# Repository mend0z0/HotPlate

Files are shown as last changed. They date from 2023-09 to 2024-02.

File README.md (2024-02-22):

## Latest update

``
Mainly working on Firmware, but modifying file structures and updating readme files are also on-going...
``

# HotPlate

Hot plate project's purpose is to control the temperature of a hot plate that is used for reflow soldering of PCBs in small numbers. The application
will support a camera for more analysis and study of the process of soldering. The application accepts Gerber, Pick&Place, and BOM, so then the 
user will have a full assembly guideline and also with the connected camera it's possible to confirm the quality and validity of placement and assembly.

## Category

__Assembly Automation__

## Features

- Image processing
- Manual assembly guide
- Controlling over any kind of heaters

## Tech Stack

### Hardware

- **MCU:** PIC18F24J50
- **Connection:** USB, SPI
- **PCB Layers:** 4Layer/s (None-controlled Impedance)
- **CAD:** KiCAD

### Firmware

- **OS:** Super loop
- **Programming Language:** C Language
- **IDE:** MPLABX

### Application

- **IDE:** Qt6
- **Operating System:** Linux/Windows
- **Device:** PC/Laptop

### Mechanical

- **CAD:** Solid Edge
- **Manufacturing Method:** 3D Printing

## Block Diagrams

SystemDesign

Hardware

Firmware

## Screenshots

### Hardware

#### Hardware CAD View

_CADView_HW

#### 3D_View

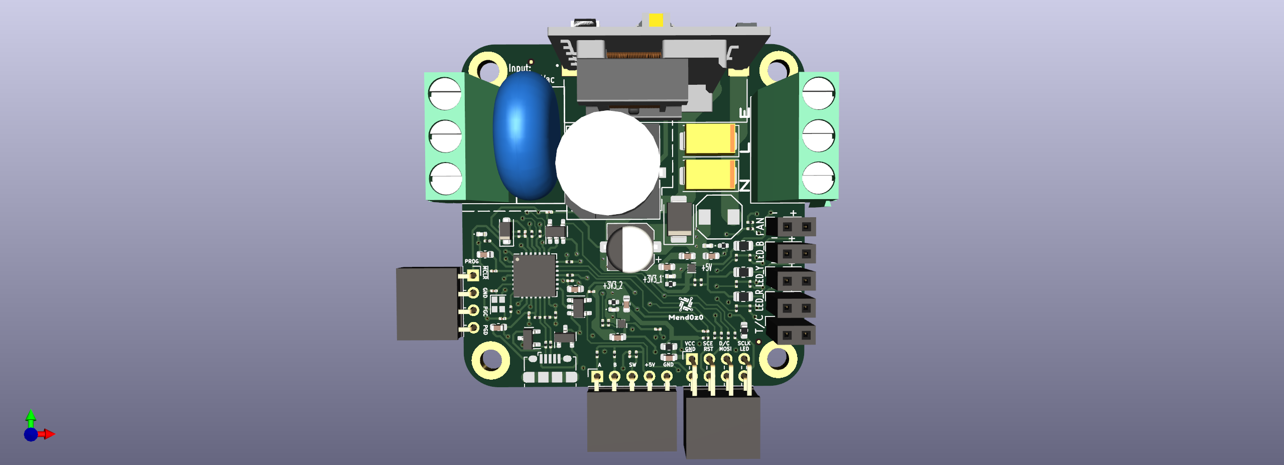
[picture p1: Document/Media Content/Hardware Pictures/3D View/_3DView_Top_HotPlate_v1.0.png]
_3DView_Top


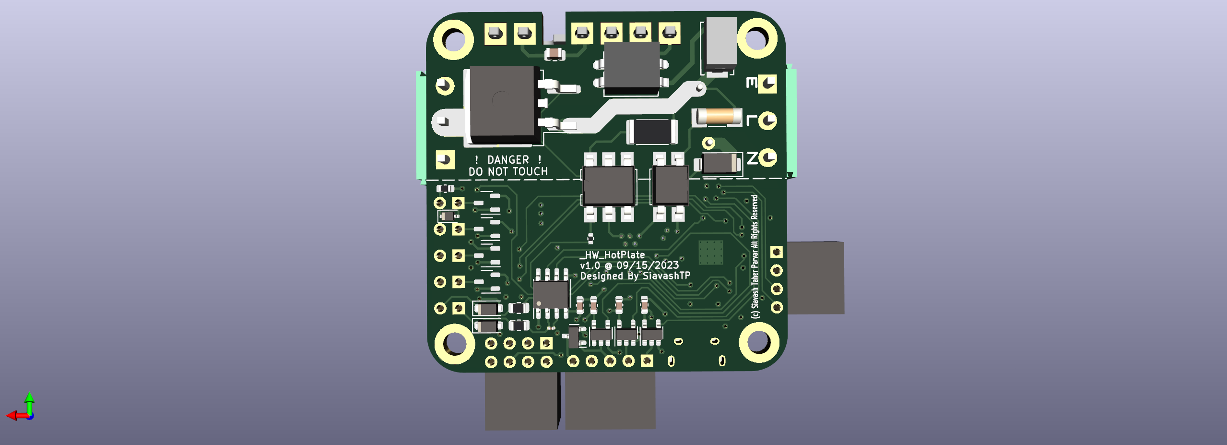
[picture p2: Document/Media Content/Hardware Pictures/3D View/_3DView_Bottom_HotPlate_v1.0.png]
_3DView_Bottom

 
#### Assembled Hardware

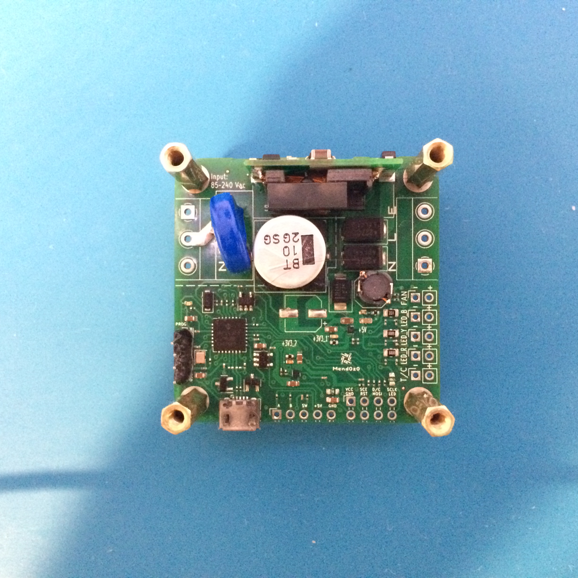
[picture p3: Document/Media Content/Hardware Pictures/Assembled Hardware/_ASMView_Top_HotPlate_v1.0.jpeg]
_ASMView_Top


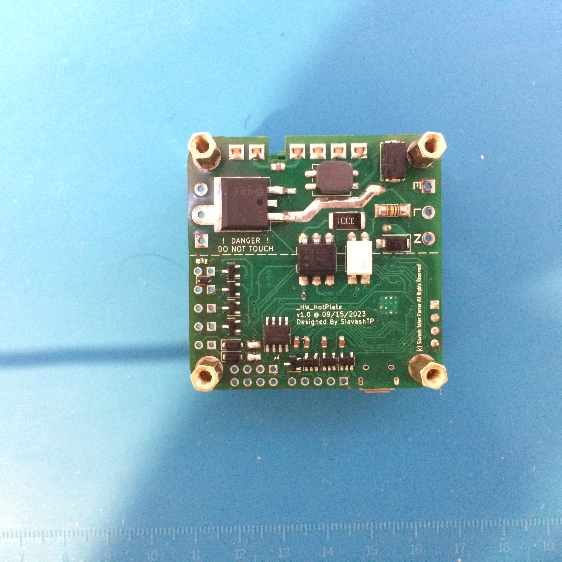
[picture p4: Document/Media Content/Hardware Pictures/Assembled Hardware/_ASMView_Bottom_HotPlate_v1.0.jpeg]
_ASMView_Bottom


### Mechanical CAD View
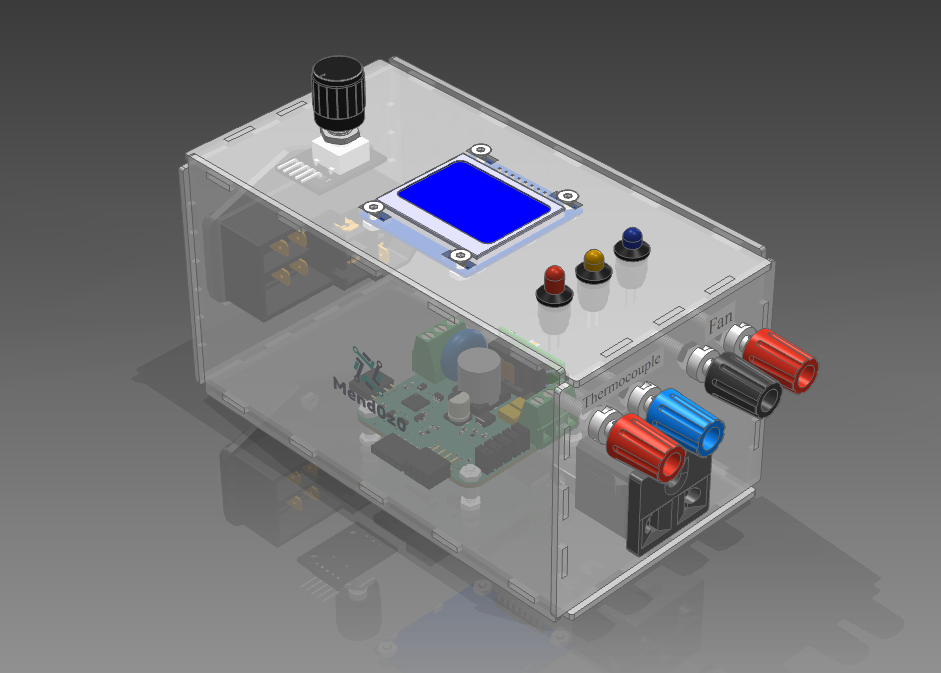
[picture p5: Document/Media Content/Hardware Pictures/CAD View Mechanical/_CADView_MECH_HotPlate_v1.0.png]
_CADView_MECH


### Final Device
_HOTPLATE_

### Application
App Screenshot

## Demo

Demo Test

## LOGO

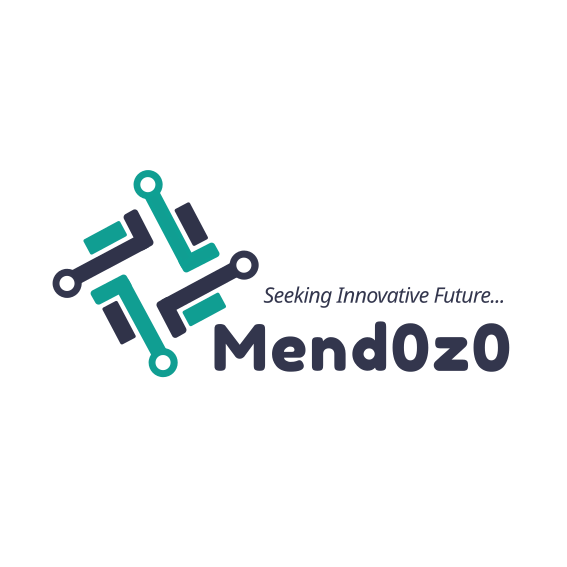
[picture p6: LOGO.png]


## Author

- [@Siavash Taher Parvar](https://www.linkedin.com/in/mend0z0)

## Support

[Support Link](https://github.com/sponsors/mend0z0)

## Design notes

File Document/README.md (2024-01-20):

## This readme file explains the folder structure of Document folder.

#### 1. Block Diagrams: 
	1. _FBD_HW_Prj_vXY.svg
	2. _FBD_SYS_Prj_vXY.svg
	3. _FBD_FW_Prj_vXY.svg

#### 2. Datasheet

#### 3. Media Content: 
	1. Application Screenshot: Screenshots of the Application

	2. Hardware Picture:
		1. 3D View:
			1. _3DView_Top_Prj_vXY.jpeg
			2. _3DView_Bottom_Prj_vXY.jpeg

		2. Assembled Hardware:
			1. _ASMView_Top_Prj_vXY.jpeg
			2. _ASMView_Bottom_Prj_vXY.jpeg

		3. CAD View Hardware:
			1._CADView_HW_Prj_vXY.svg
   
   		4. CAD View Mechanical:
     			1._CADView_MECH_Prj_vXY.svg
	
		5. Full Device
  			1._Prj_vXY.png

	3. Videos
 		1. _VID_Prj_Title_vXY.mp4

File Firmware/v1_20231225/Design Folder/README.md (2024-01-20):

# TODO List

HotPlate firmware project todo list.

## Tasks

- #### MUST to DO (List the works that proper working of project depends on these tasks) :
    - Drawing peripheral functions block diagram (USB, TIMER 0, TIMER 1, TIMER 2, TIMER 3, GPIO, SPI, WDT, EXTI, RTC)
    - Drawing each module/device API/Init functions block diagram (LEDs, FAN, TRIAC, PCD8544, KY-040, MAX31855, Ind LED)
    - Writing C code for the drawn block diagram
    - Writing C code for the ISR
    - Writing C code for the modules/devices
    - Drawing a test scenario for connected modules/devices
    - Writing C code the test scenario block diagram
    - Drawing block diagram for main super-loop
    - Writing C code for the main super-loop block diagram
    - 
    - 
    - 
    - 
    - 
    - 
    - 
    - 
    - 
    - 
    - 
    - 
    - 
    - 
    - 
    - 
    - 
    - 
    - 
    - 
    - 
- #### Important (List the works that efficient and optimized functionality of project depends on these tasks):
    - 
    -
    - 
- #### General (List tasks that are good to be done but the functionality of project doesn't depend on these):
    - 
    -
    -

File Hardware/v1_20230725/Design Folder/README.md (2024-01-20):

# TODO list

HotPlate hardware project todo list.

## Tasks

- #### MUST DO (List the works that proper working of project depends on these tasks):
    - Removing the Header 4x2 from Mechanical parts, and replacing with only 1 recept 1x8.
    - Adding all the mechanical components to the library and schematic.
    - Exporting all the required outputs and finalizing the hardware project.
    - Designing the enclosure in Solidedge.
    - Correcting the stencil outputs. (Next revision)
    - 
- #### Important (List the works that efficient and optimized functionality of project depends on these tasks):
    - Adding 1 more RED LED for +5v power to be placed on the enclosure. (Mechanical parts) (Next revision)
    - Adding 1 more header (2x1, P1.27mm), for +5v output in schematic. (Next revision)
    - Adding Test points for each output power. (Next revision)
    - Correcting the prog pin order according to the output of the programmer. (Next revision)
    - Sizing up the components to 0603 package. (Next revision)
    - Changing the LDO to some bigger package, maybe TL... (Next revision)
    - Modifying the component placement for sure :) (Next revision)
    - Changing the big cap (10uF_400V) to THD. (Next revision)
    - 
- #### General (List tasks that are good to be done but the functionality of project doesn't depend on these):
    - 
    -
    -

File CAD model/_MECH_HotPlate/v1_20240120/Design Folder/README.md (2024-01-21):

# TODO list

A brief description of this todo list belongs to what project

## Tasks

- #### MUST DO (List the works that proper working of project depends on these tasks):
    - Finding Nokia 3D model
    - Finding LEDs (Green, Red, Orange) 3D parts, 5mm
    - Finding LED holder 3d part
    - Rotary encoder 3d part + Knobe
    - Standoff 3d part
    - Screw 3d part
    - Board dimension 150*60*80mm
    - Banana plug 3D part
    - 
    - 
- #### Important (List the works that efficient and optimized functionality of project depends on these tasks):
    - 
    -
    - 
- #### General (List tasks that are good to be done but the functionality of project doesn't depend on these):
    - 
    -
    -

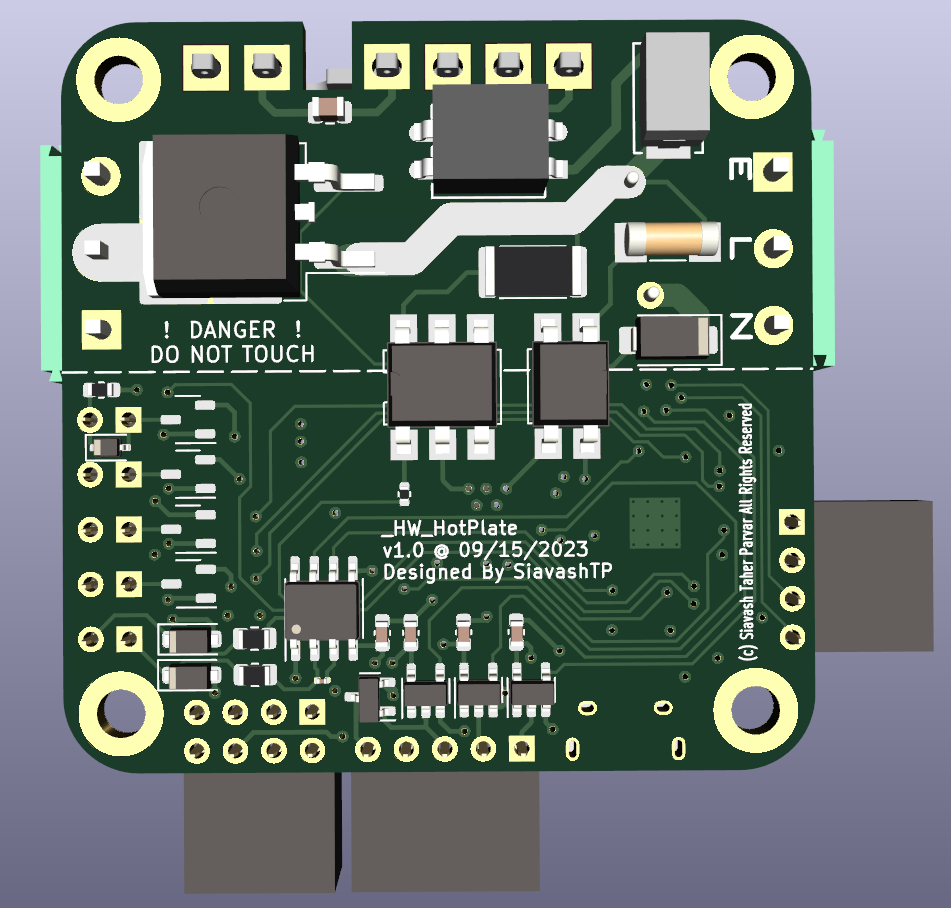
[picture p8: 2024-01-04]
Hardware/v1_20230725/Design Folder/_HW_HotPlate/Output files/3D View/_3DView_Bottom_HotPlate_v1.0 - Copy.png

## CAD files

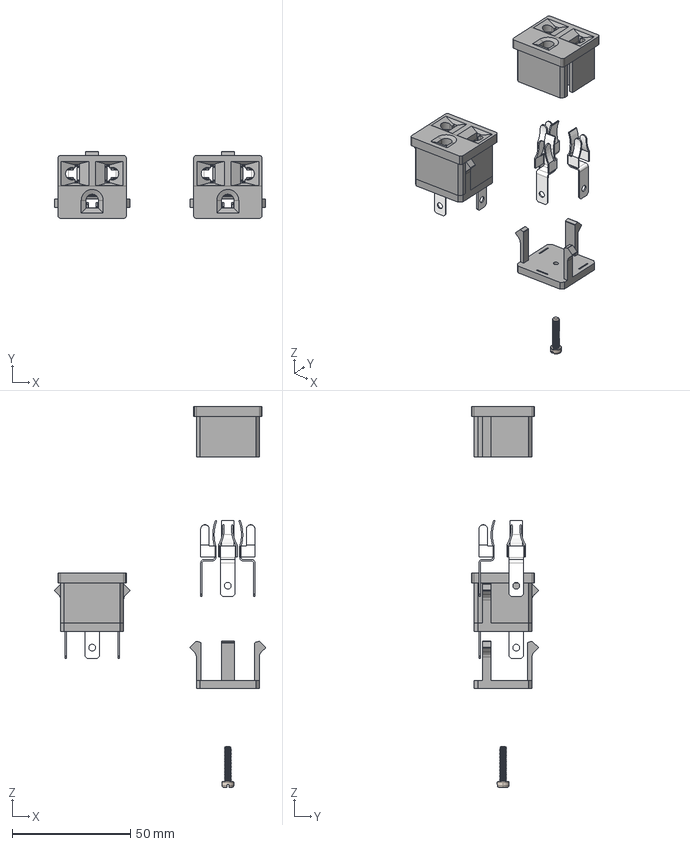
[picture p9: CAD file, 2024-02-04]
CAD model/_MECH_HotPlate/v1_20240120/Design Folder/_MECH_HotPlate/socket-supply.stp
89.4 x 28.2 x 161.2 mm
socket-suplay
Explod Geometry
bak x 2
Screw x 2
pin x 6

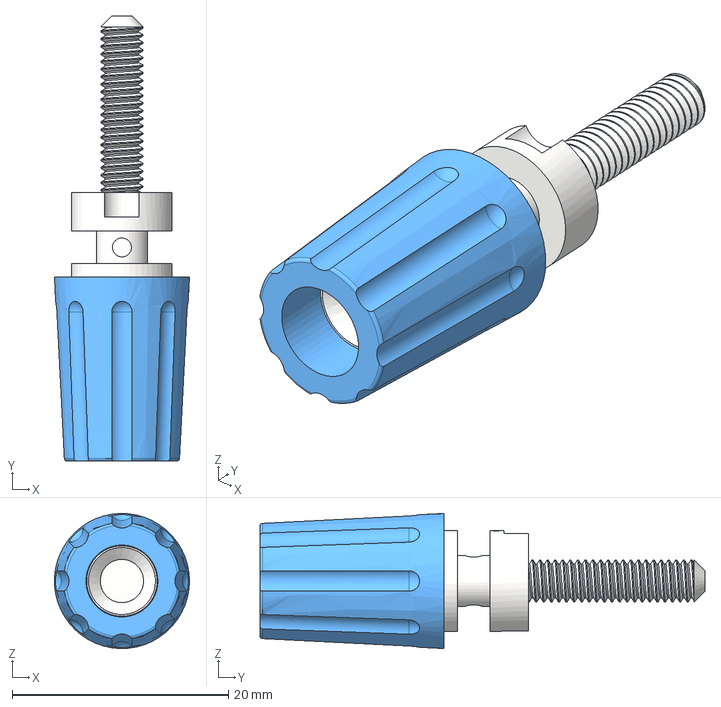
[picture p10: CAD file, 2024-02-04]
CAD model/_MECH_HotPlate/v1_20240120/Design Folder/_MECH_HotPlate/Banana Socket (Blue).step
12.5 x 41.2 x 12.5 mm

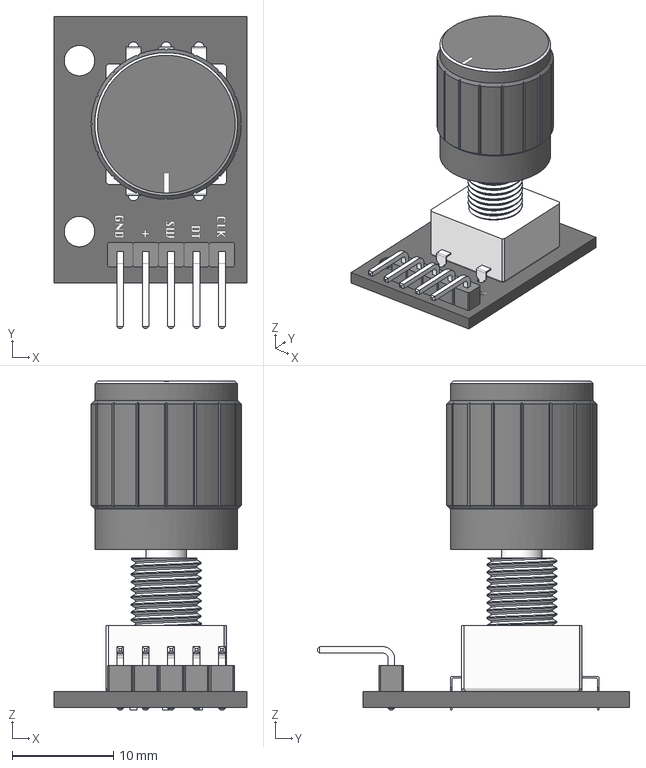
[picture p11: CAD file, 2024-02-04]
CAD model/_MECH_HotPlate/v1_20240120/Design Folder/_MECH_HotPlate/Rotary Encoder - KY-040.step
19.0 x 30.8 x 32.4 mm

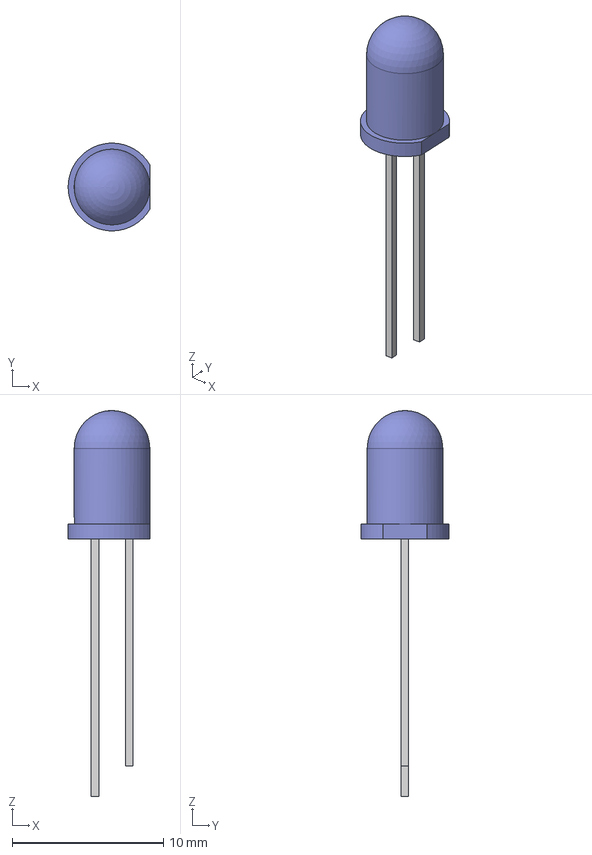
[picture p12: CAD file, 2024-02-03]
CAD model/_MECH_HotPlate/v1_20240120/Design Folder/_MECH_HotPlate/HernanMH_LED 5mm Azul_.step
5.40 x 5.79 x 25.5 mm

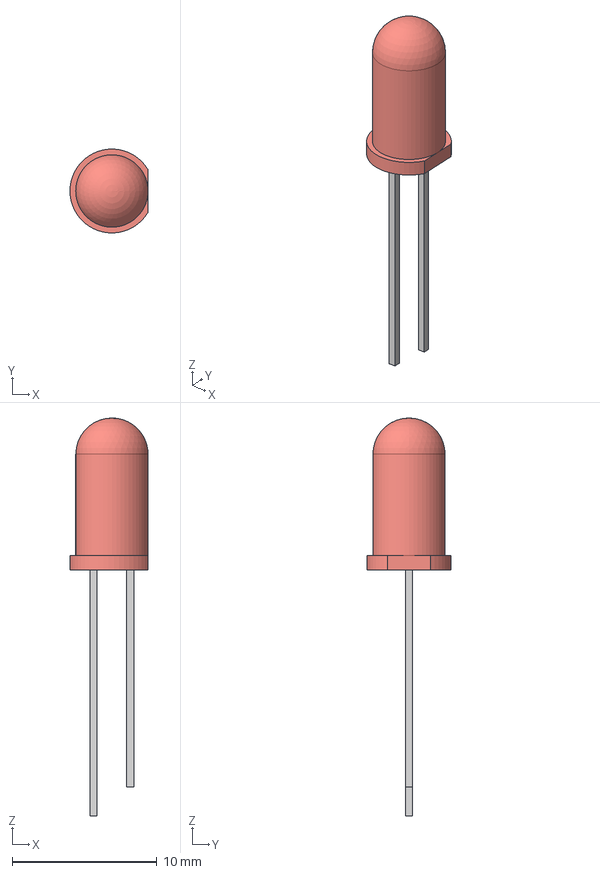
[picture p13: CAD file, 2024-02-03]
CAD model/_MECH_HotPlate/v1_20240120/Design Folder/_MECH_HotPlate/Led 5mm rojo.step
5.40 x 5.79 x 27.5 mm

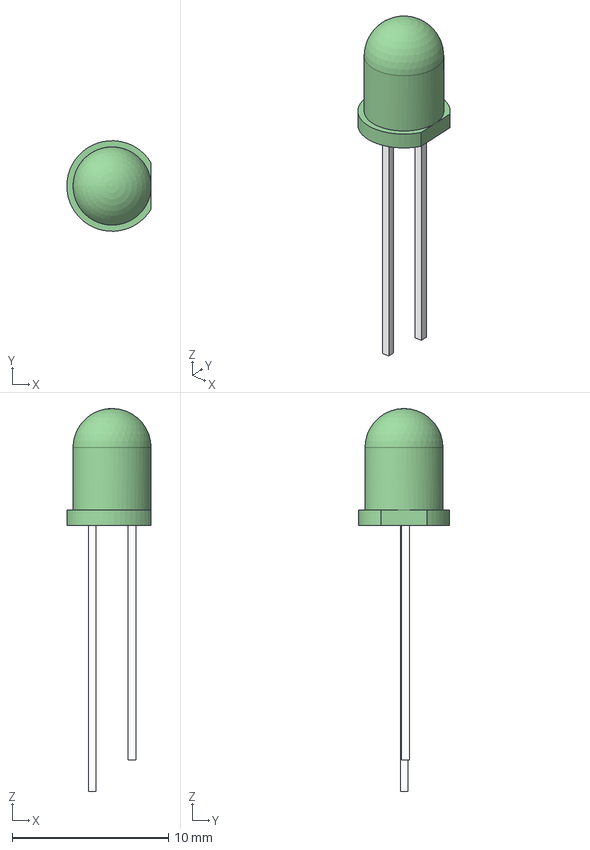
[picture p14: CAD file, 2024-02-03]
CAD model/_MECH_HotPlate/v1_20240120/Design Folder/_MECH_HotPlate/JesusMC_led 5mm v1.step
5.40 x 5.79 x 24.5 mm

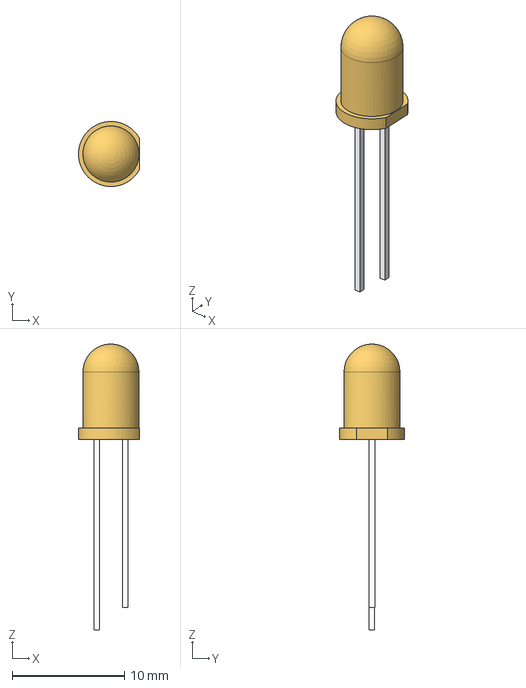
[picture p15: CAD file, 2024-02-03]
CAD model/_MECH_HotPlate/v1_20240120/Design Folder/_MECH_HotPlate/LED5MM v1.step
5.44 x 5.80 x 25.5 mm

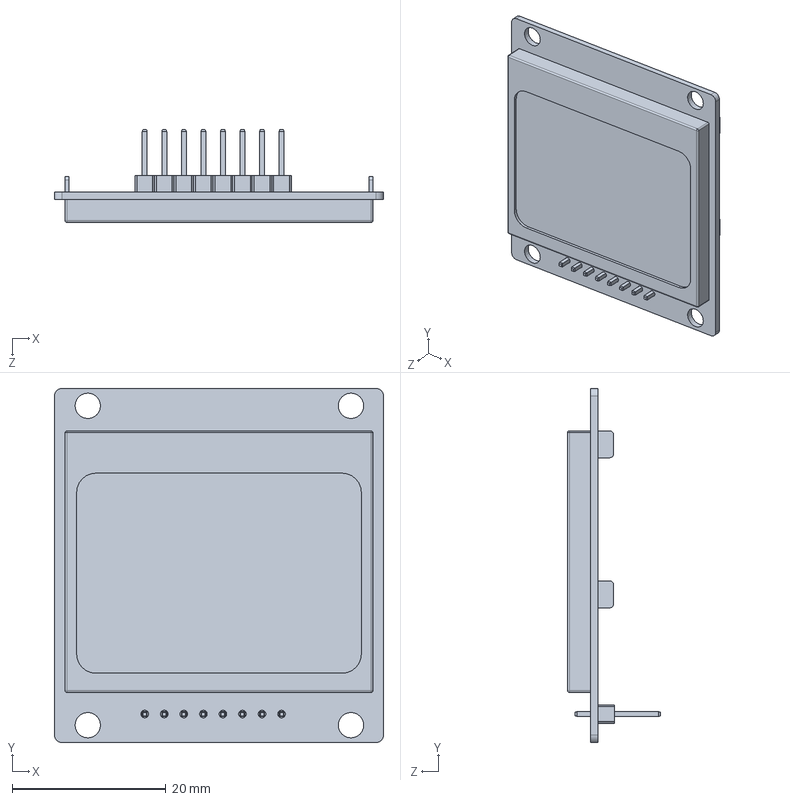
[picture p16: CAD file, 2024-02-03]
CAD model/_MECH_HotPlate/v1_20240120/Design Folder/_MECH_HotPlate/LCD Nokia 5110 Adafruit.SLDPRT
42.8 x 46.0 x 12.1 mm

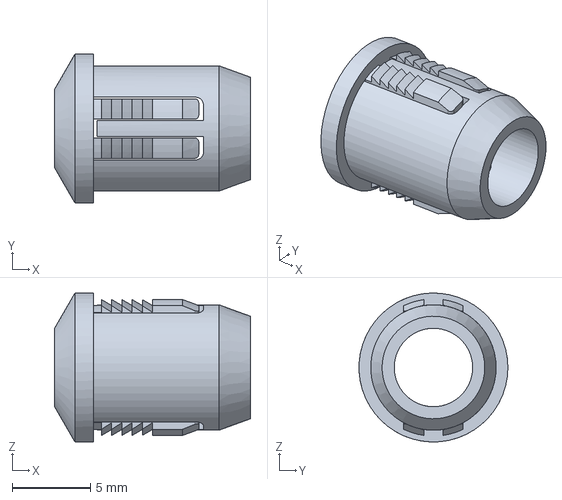
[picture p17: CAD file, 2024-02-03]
CAD model/_MECH_HotPlate/v1_20240120/Design Folder/_MECH_HotPlate/rtf_5010.stp
12.5 x 9.49 x 9.50 mm

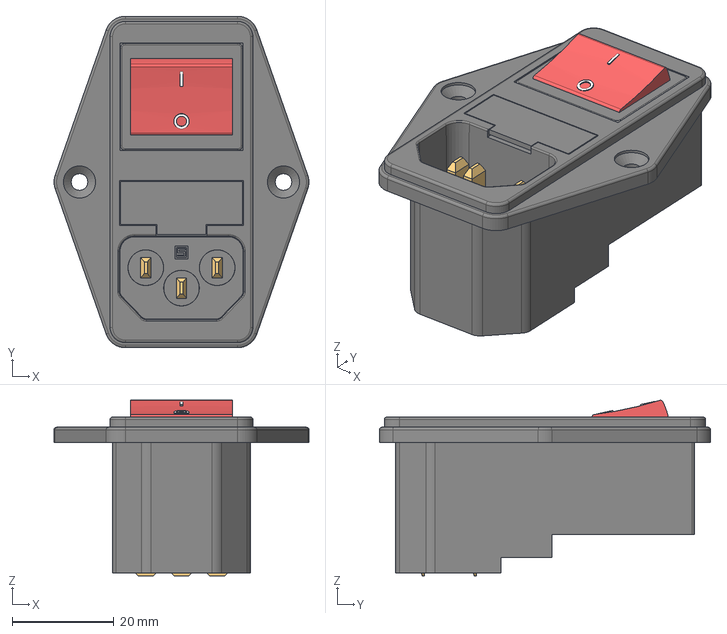
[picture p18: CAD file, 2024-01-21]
CAD model/_MECH_HotPlate/v1_20240120/Design Folder/_MECH_HotPlate/Schurter - 4304.6071 Power Entry Connector Receptacle wth Fuse.stp
50.0 x 65.0 x 34.4 mm

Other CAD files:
CAD model/_MECH_HotPlate/v1_20240120/Design Folder/_MECH_HotPlate/Banana Socket (Black).step
CAD model/_MECH_HotPlate/v1_20240120/Design Folder/_MECH_HotPlate/Banana Socket (Red).step
CAD model/_MECH_HotPlate/v1_20240120/Design Folder/_MECH_HotPlate/m4 lock nut.prt

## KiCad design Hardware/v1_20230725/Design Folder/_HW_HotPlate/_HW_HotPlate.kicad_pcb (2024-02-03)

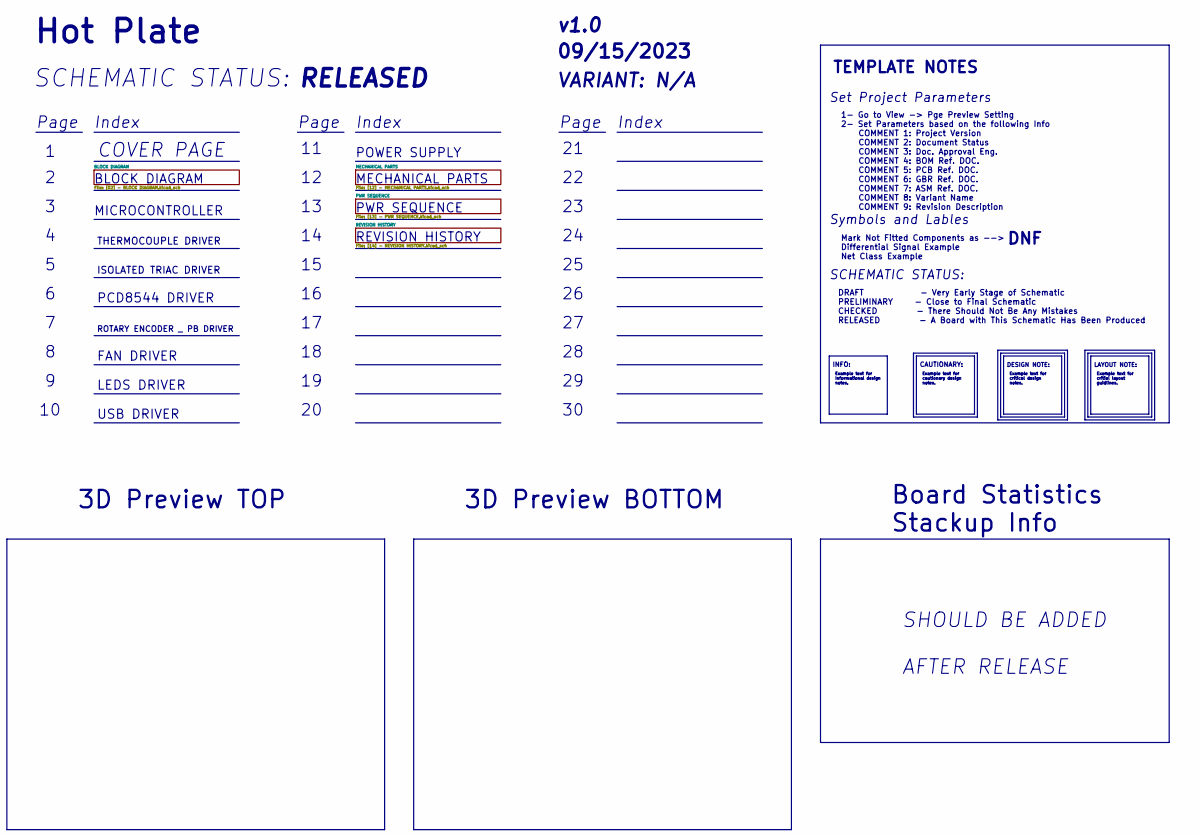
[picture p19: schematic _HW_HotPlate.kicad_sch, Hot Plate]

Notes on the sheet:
USB DRIVER
SHOULD BE ADDED AFTER RELEASE
Set Project Parameters
PCD8544 DRIVER
PWR SEQUENCE
VARIANT: ${COMMENT8}
${REVISION}
Index
Example text for critial layout guidlines.
${TITLE}
DESIGN NOTE:
Page
Board Statistics Stackup Info
REVISION HISTORY
${COMMENT2}
COVER PAGE
SCHEMATIC STATUS:
ISOLATED TRIAC DRIVER
MICROCONTROLLER
LEDS DRIVER
Symbols and Lables
TEMPLATE NOTES
THERMOCOUPLE DRIVER
Mark Not Fitted Components as --> Differential Signal Example Net Class Example
${ISSUE_DATE}
Example text for critical design notes.
Example text for Informational design notes.
Example text for cautionary design notes.
INFO:
SCHEMATIC STATUS:
BLOCK DIAGRAM
FAN DRIVER
3D Preview BOTTOM
1- Go to View -> Pge Preview Setting 2- Set Parameters based on the following Info COMMENT 1: Project Version COMMENT 2: Document Status COMMENT 3: Doc. Approval Eng. COMMENT 4: BOM Ref. DOC. COMMENT 5: PCB Ref. DOC. COMMENT 6: GBR Ref. DOC. COMMENT 7: ASM Ref. DOC. COMMENT 8: Variant Name COMMENT 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
LAYOUT NOTE:
CAUTIONARY:
POWER SUPPLY
DRAFT - Very Early Stage of Schematic PRELIMINARY - Close to Final Schematic CHECKED - There Should Not Be Any Mistakes RELEASED - A Board with This Schematic Has Been Produced
MECHANICAL PARTS
DNF

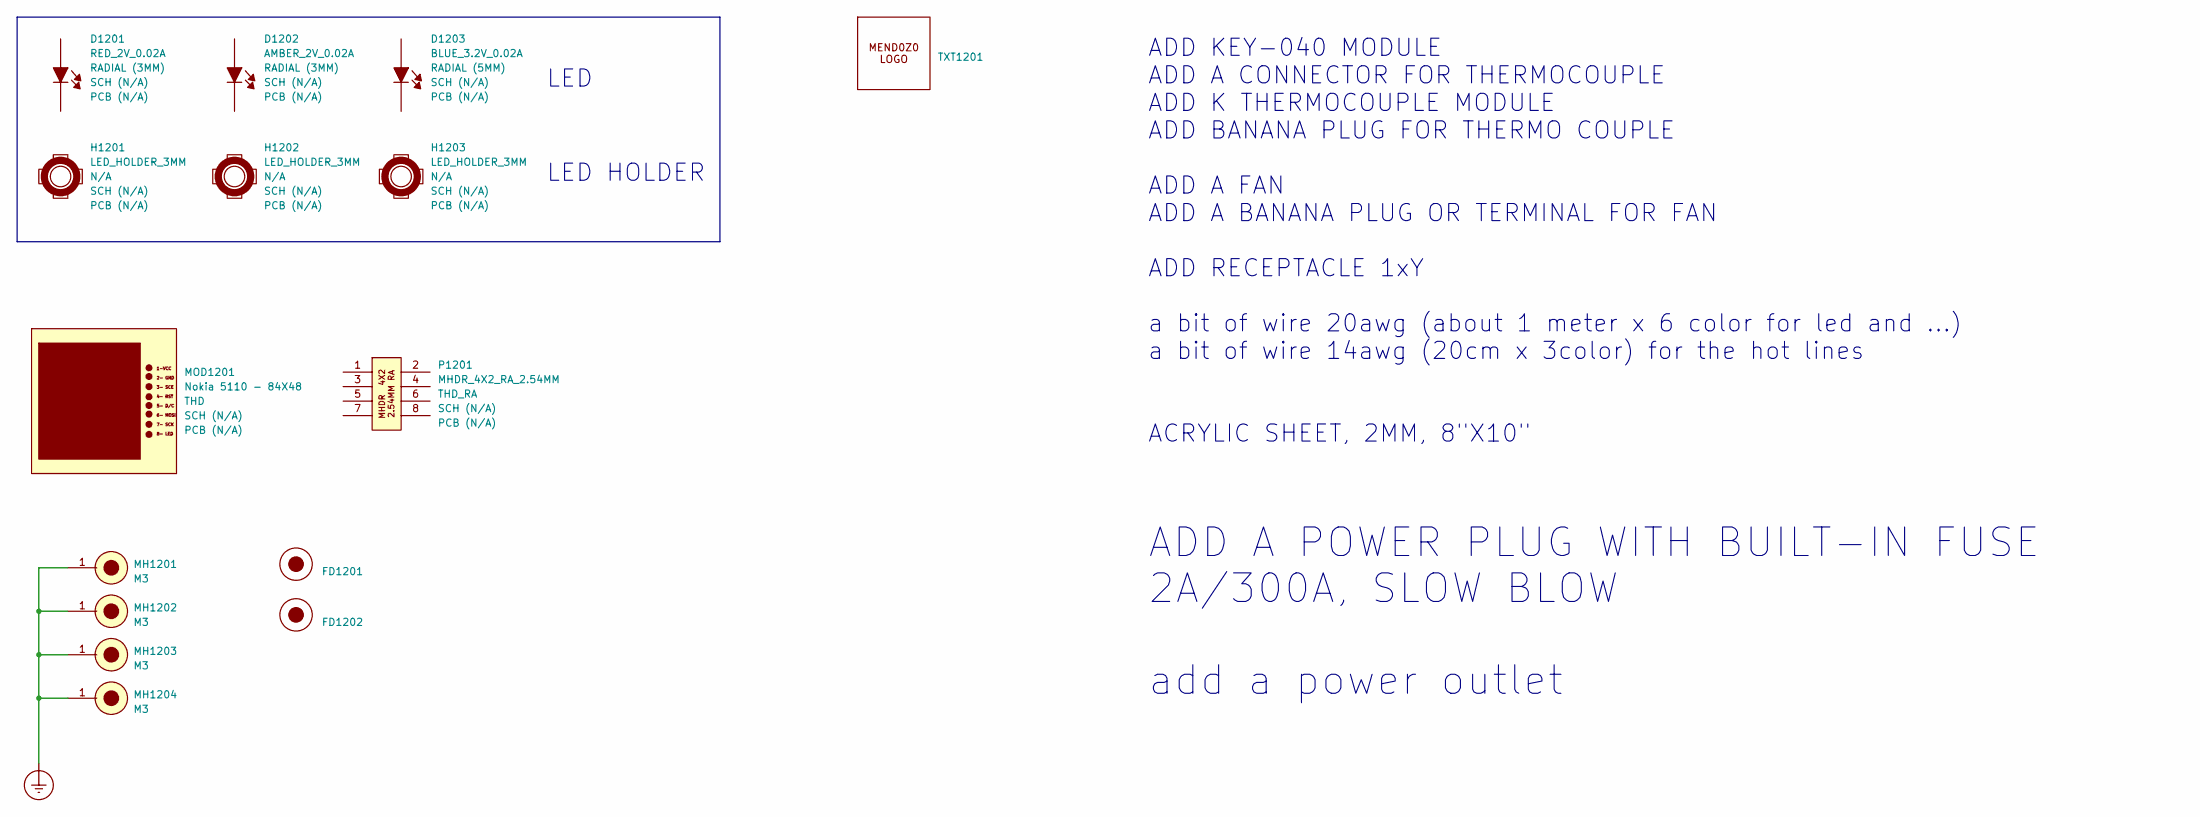
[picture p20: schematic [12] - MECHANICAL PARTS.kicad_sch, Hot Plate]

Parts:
D1201: RED_2V_0.02A; LED_D3.0mm; Part Number (Manufactur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 WP7113ID
D1202: AMBER_2V_0.02A; LED_D3.0mm; Part Number (Manufactur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 BL-BJC1V4V-AT
D1203: BLUE_3.2V_0.02A; LED_D5.0mm; Part Number (Manufactur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 151051BS04000
FD1201, FD1202: Fiducial_0.5mm_Mask1mm
H1201, H1202, H1203: LED_HOLDER_3MM; Part Number (Manufactur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 SSH-LX3050
MH1201, MH1202, MH1203, MH1204: M3; MountingHole_3.2mm_M3_DIN965_Pad_TopBottom
MOD1201: Nokia 5110 - 84X48; Part Number Graphic LCD 84x48 - Nokia 5110
P1201: MHDR_4X2_RA_2.54MM; PinHeader_2x04_P2.54mm_Horizontal; Part Number (Manufactur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 PHED-RS008G1ABOGA-C006
TXT1201: Mend0z0_Logo

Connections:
Earth_Protective: MH1201.1, MH1202.1, MH1203.1, MH1204.1; also elsewhere on the board

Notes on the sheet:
LED
ADD KEY-040 MODULE ADD A CONNECTOR FOR THERMOCOUPLE ADD K THERMOCOUPLE MODULE ADD BANANA PLUG FOR THERMO COUPLE ADD A FAN ADD A BANANA PLUG OR TERMINAL FOR FAN ADD RECEPTACLE 1xY a bit of wire 20awg (about 1 meter x 6 color for led and ...) a bit of wire 14awg (20cm x 3color) for the hot lines ACRY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
LED HOLDER
ADD A POWER PLUG WITH BUILT-IN FUSE 2A/300A, SLOW BLOW add a power outlet

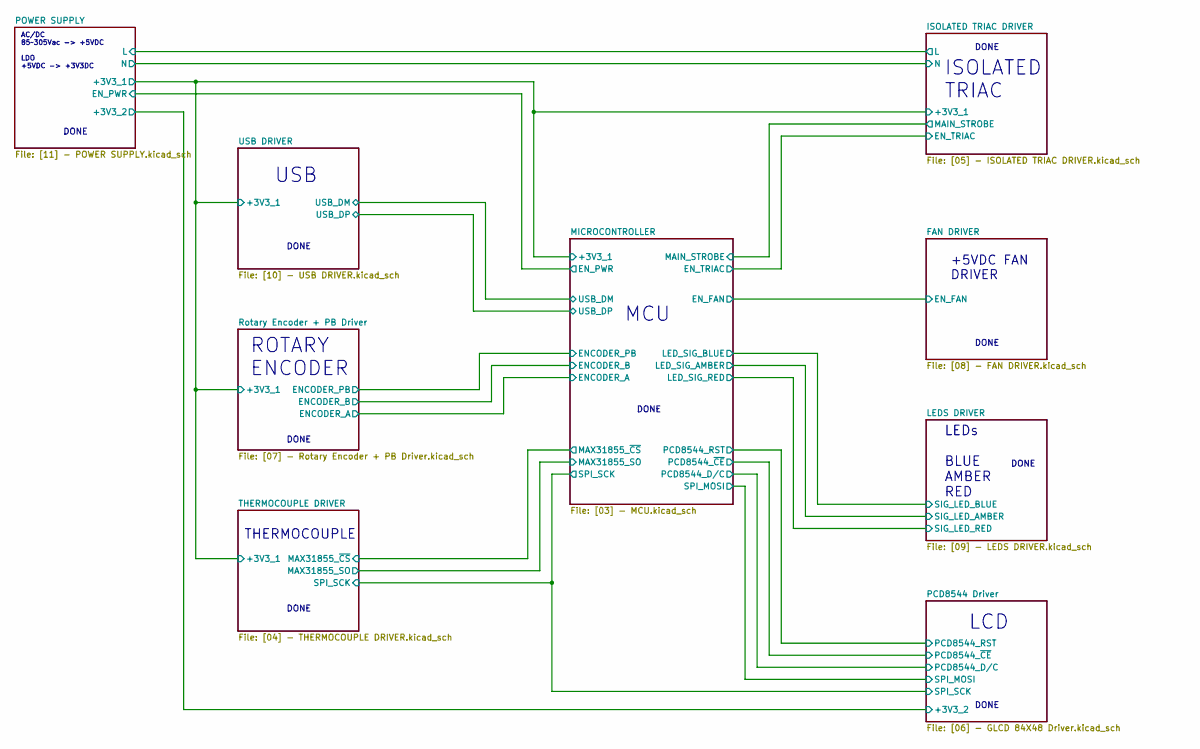
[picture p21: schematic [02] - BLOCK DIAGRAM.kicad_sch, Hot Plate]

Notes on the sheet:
DONE
MCU
THERMOCOUPLE
AC/DC 85~305Vac -> +5VDC LDO +5VDC -> +3V3DC
USB
LCD
ROTARY ENCODER
ISOLATED TRIAC
LEDs BLUE AMBER RED
+5VDC FAN DRIVER

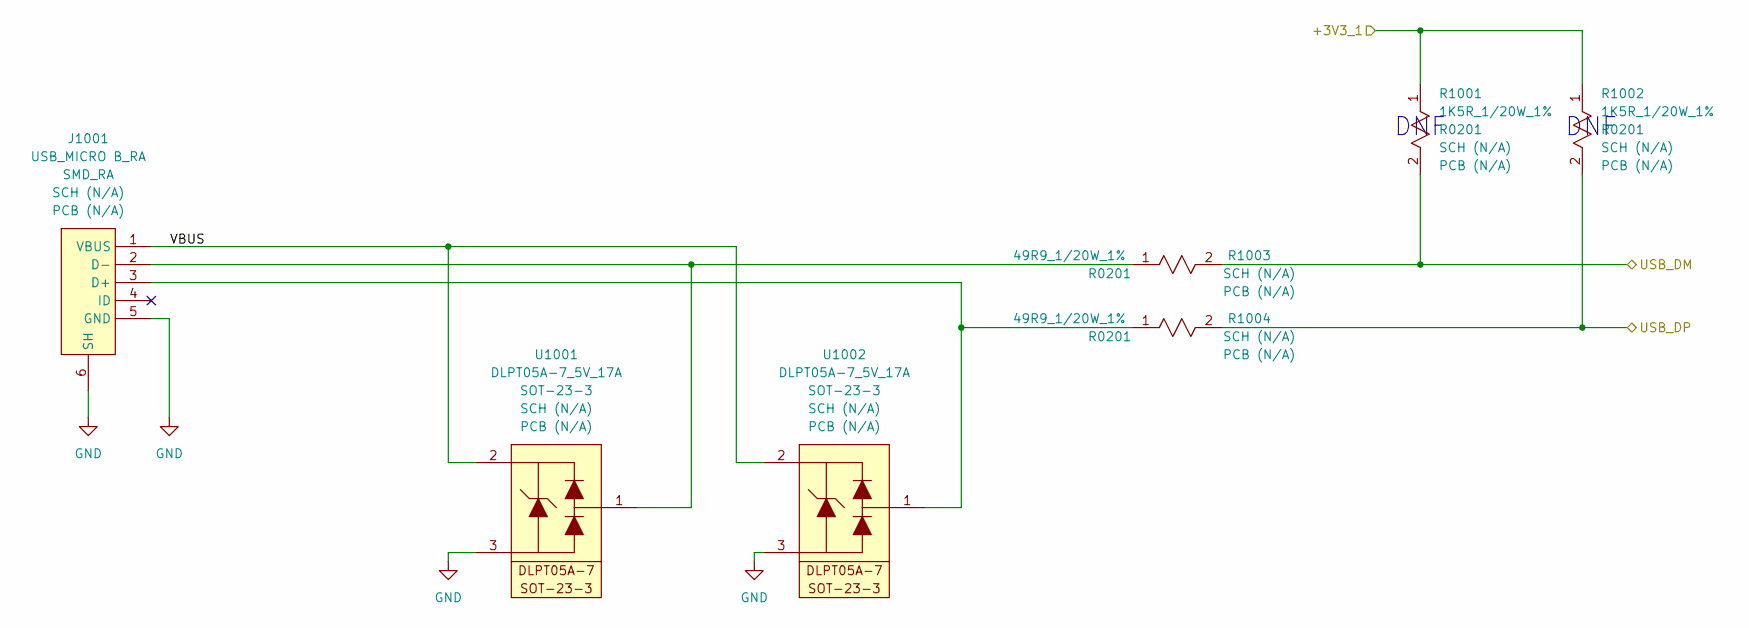
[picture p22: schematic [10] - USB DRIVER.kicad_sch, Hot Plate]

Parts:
J1001: USB_MICRO B_RA; USB_Micro-B_Amphenol_10118194_Horizontal; Part Number (Manufactur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 10118194-0001LF
R1001, R1002: 1K5R_1/20W_1%; R_0201_0603Metric; Part Number (Manufactur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 RC0201FR-071K4L
R1003, R1004: 49R9_1/20W_1%; R_0201_0603Metric; Part Number (Manufactur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 RMCF0201FT49R9
U1001, U1002: DLPT05A-7_5V_17A; SOT-23; Part Number (Manufactur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 DLPT05A-7

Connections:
/BLOCK DIAGRAM/ISOLATED TRIAC DRIVER/+3V3_1: R1001.1, R1002.1; also elsewhere on the board
/BLOCK DIAGRAM/MICROCONTROLLER/USB_DM: R1001.2, R1003.2; also elsewhere on the board
/BLOCK DIAGRAM/MICROCONTROLLER/USB_DP: R1002.2, R1004.2; also elsewhere on the board
/BLOCK DIAGRAM/USB DRIVER/VBUS: J1001.1 (VBUS), U1001.2, U1002.2
unnamed: J1001.3 (D+), R1004.1, U1002.1
unnamed: J1001.2 (D-), R1003.1, U1001.1

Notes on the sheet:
DNF

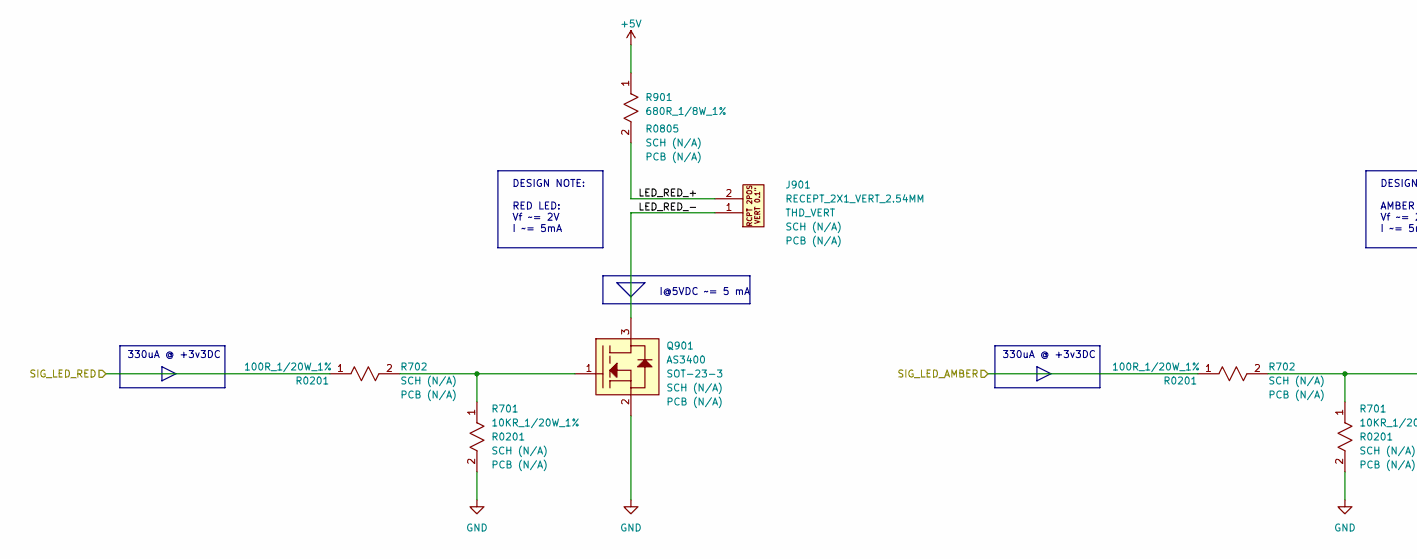
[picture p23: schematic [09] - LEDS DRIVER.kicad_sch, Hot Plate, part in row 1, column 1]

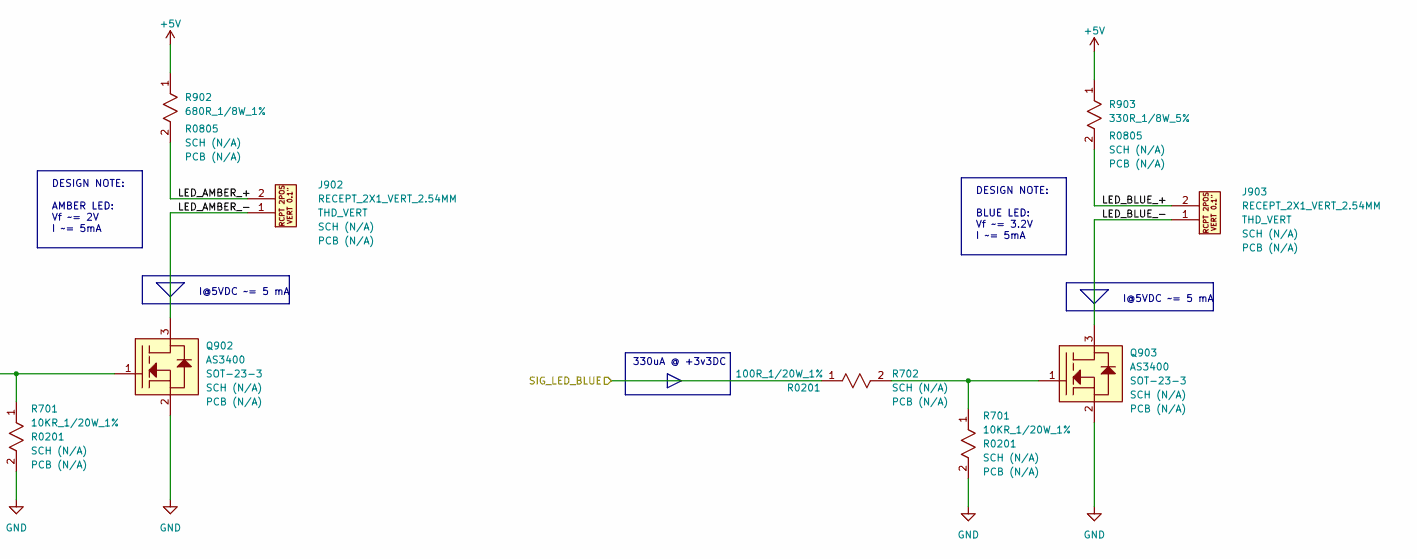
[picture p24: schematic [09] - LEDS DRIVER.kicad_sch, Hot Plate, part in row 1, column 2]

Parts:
J901, J902, J903: RECEPT_2X1_VERT_2.54MM; PinSocket_1x02_P2.54mm_Vertical; Part Number (Manufactur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 RS1-02-G
Q901, Q902, Q903: AS3400; SOT-23; Part Number (Manufactur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 AS3400
R701: 10KR_1/20W_1%; R_0201_0603Metric; Part Number (Manufactur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 RMCF0201FT10K0
R702: 100R_1/20W_1%; R_0201_0603Metric; Part Number (Manufactur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 RMCF0201FT100R
R901, R902: 680R_1/8W_1%; R_0805_2012Metric; Part Number (Manufactur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 AC0805FR-07680RL
R903: 330R_1/8W_5%; R_0805_2012Metric; Part Number (Manufactur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 CRGCQ0805J330R

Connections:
/BLOCK DIAGRAM/LEDS DRIVER/LED_AMBER_+: J902.2, R902.2
/BLOCK DIAGRAM/LEDS DRIVER/LED_AMBER_-: J902.1, Q902.3
/BLOCK DIAGRAM/LEDS DRIVER/LED_RED_+: J901.2, R901.2
/BLOCK DIAGRAM/LEDS DRIVER/LED_RED_-: J901.1, Q901.3
unnamed 68: R702.1; also elsewhere on the board

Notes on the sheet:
DESIGN NOTE: AMBER LED: Vf ~= 2V I ~= 5mA
I@5VDC ~= 5 mA
DESIGN NOTE: BLUE LED: Vf ~= 3.2V I ~= 5mA
330uA @ +3v3DC
DESIGN NOTE: RED LED: Vf ~= 2V I ~= 5mA

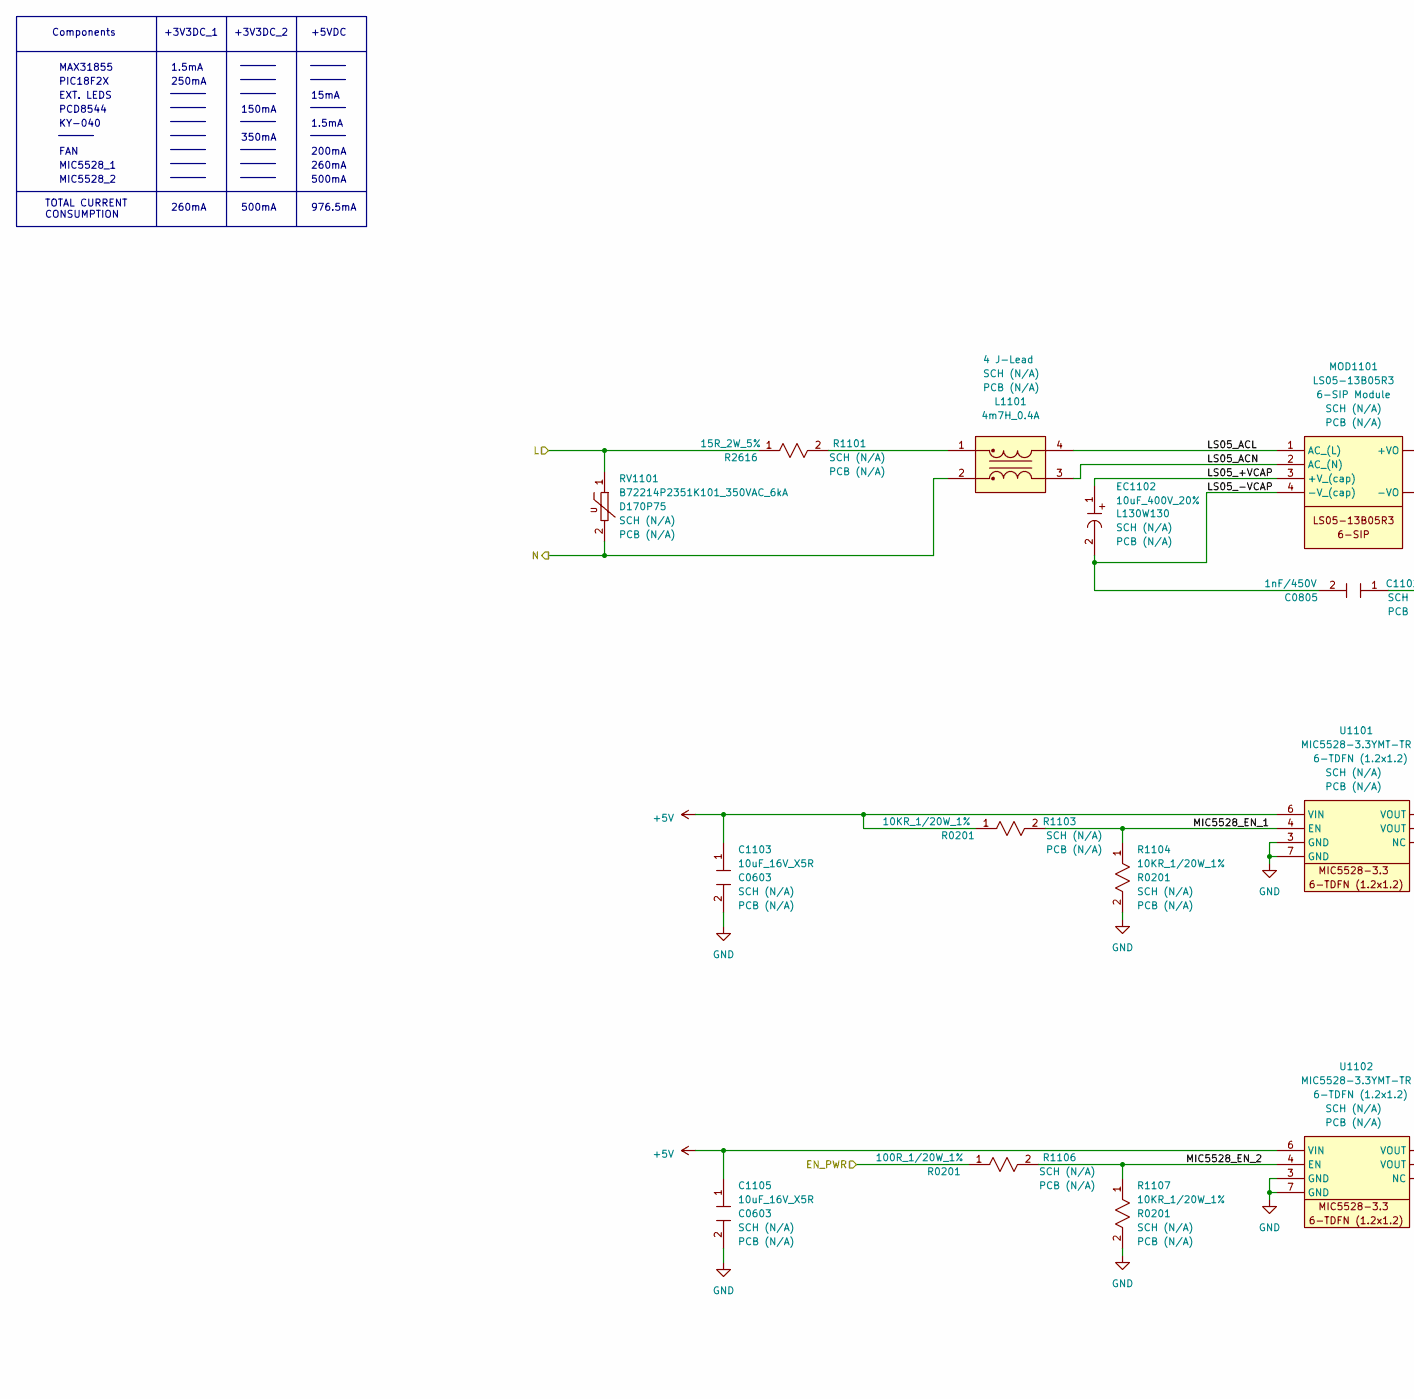
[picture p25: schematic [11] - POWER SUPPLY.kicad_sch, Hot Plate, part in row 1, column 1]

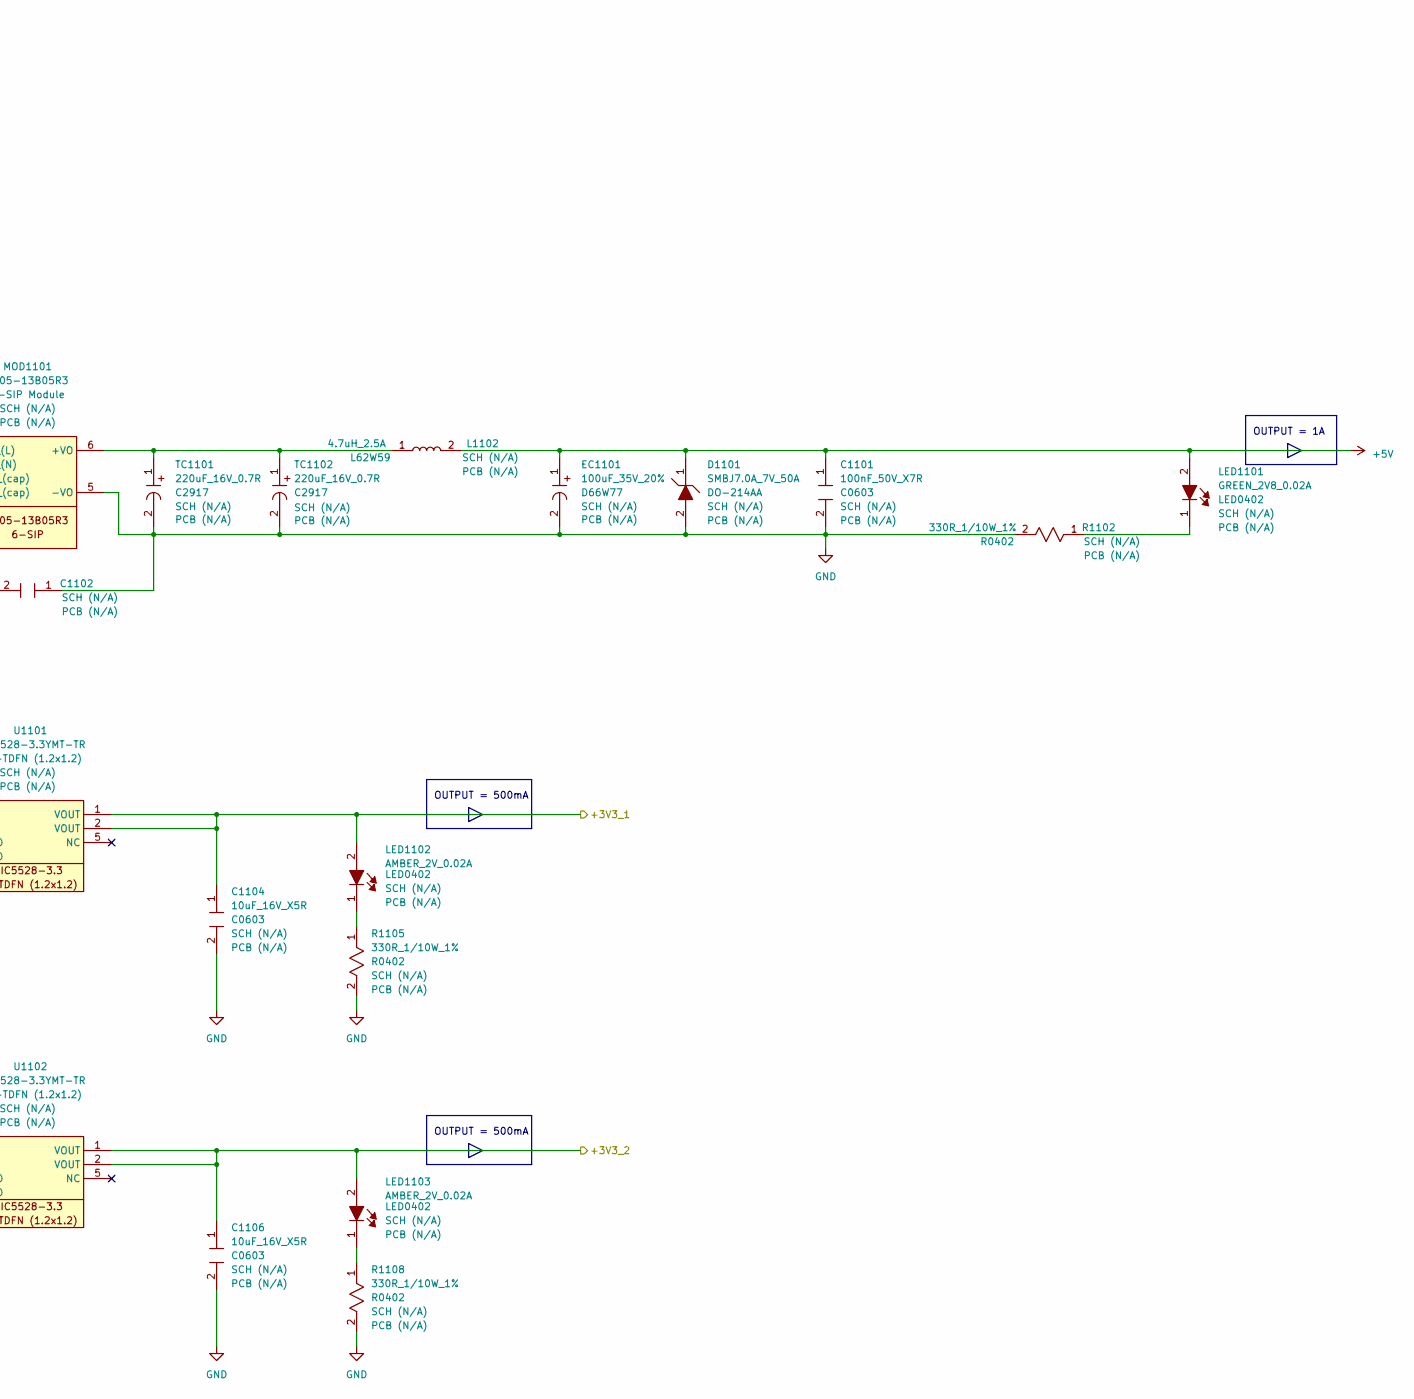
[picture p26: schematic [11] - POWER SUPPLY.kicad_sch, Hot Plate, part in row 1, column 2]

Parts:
C1101: 100nF_50V_X7R; C_0603_1608Metric; Part Number (Manufactur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 CL10B104KB8NNNC
C1102: 1nF/450V; C_0805_2012Metric; Part Number CGA4C4C0G2W102J060AE
C1103, C1104, C1105, C1106: 10uF_16V_X5R; C_0603_1608Metric; Part Number (Manufactur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 GRT188R61C106KE13J
D1101: SMBJ7.0A_7V_50A; D_SMB; Part Number (Manufactur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 SMBJ7.0A
EC1101: 100uF_35V_20%; CP_Elec_6.3x7.7; Part Number (Manufactur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 AFK107M35X16T-F
EC1102: 10uF_400V_20%; CAP_S-V_12P5X13P5_RUB; Part Number (Manufactur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 400SGV10M12.5X13.5
L1101: 4m7H_0.4A; IND_50XXXC_MUR; Part Number (Manufactur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 50475C
L1102: 4.7uH_2.5A; IND_6045_TDK; Part Number (Manufactur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 CLF6045T-4R7N-H
LED1101: GREEN_2V8_0.02A; LED_0402_1005Metric; Part Number (Manufactur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 B2841NG--05D000514U1930
LED1102, LED1103: AMBER_2V_0.02A; LED_0402_1005Metric; Part Number (Manufactur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 B2841UY--20D000414U1930
MOD1101: LS05-13B05R3; CONV_LS05-13B05R3; Part Number (Manufactur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 LS05-13B05R3
R1101: 15R_2W_5%; RES_SMF2_TYCO_TYC; Part Number (Manufactur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 SMW215RJT
R1102, R1105, R1108: 330R_1/10W_1%; R_0402_1005Metric; Part Number (Manufactur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 ERJ-2RKF3300X
R1103, R1104, R1107: 10KR_1/20W_1%; R_0201_0603Metric; Part Number (Manufactur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 RMCF0201FT10K0
R1106: 100R_1/20W_1%; R_0201_0603Metric; Part Number (Manufactur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 RMCF0201FT100R
RV1101: B72214P2351K101_350VAC_6kA; RV_Disc_D16.5mm_W6.7mm_P7.5mm; Part Number (Manufactur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 B72214P2351K101
TC1101, TC1102: 220uF_16V_0.7R; CP_EIA-7343-30_AVX-N; Part Number (Manufactur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 F931C227MNC
U1101, U1102: MIC5528-3.3YMT-TR; DFN-6-1EP_1.2x1.2mm_P0.4mm_EP0.3x0.94mm_PullBack; Part Number (Manufactur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 MIC5528-3.3YMT-TR

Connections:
/BLOCK DIAGRAM/ISOLATED TRIAC DRIVER/+3V3_1: C1104.1, LED1102.2, U1101.1 (VOUT), U1101.2 (VOUT); also elsewhere on the board
/BLOCK DIAGRAM/ISOLATED TRIAC DRIVER/L_IN: R1101.1, RV1101.1; also elsewhere on the board
/BLOCK DIAGRAM/ISOLATED TRIAC DRIVER/N: L1101.2, RV1101.2; also elsewhere on the board
/BLOCK DIAGRAM/MICROCONTROLLER/EN_PWR: R1106.1; also elsewhere on the board
/BLOCK DIAGRAM/PCD8544 Driver/+3V3_2: C1106.1, LED1103.2, U1102.1 (VOUT), U1102.2 (VOUT); also elsewhere on the board
/BLOCK DIAGRAM/POWER SUPPLY/LS05_+VCAP: EC1102.1, MOD1101.3 (+V_(cap))
/BLOCK DIAGRAM/POWER SUPPLY/LS05_-VCAP: C1102.2, EC1102.2, MOD1101.4 (-V_(cap))
/BLOCK DIAGRAM/POWER SUPPLY/LS05_ACL: L1101.4, MOD1101.1 (AC_(L))
/BLOCK DIAGRAM/POWER SUPPLY/LS05_ACN: L1101.3, MOD1101.2 (AC_(N))
/BLOCK DIAGRAM/POWER SUPPLY/MIC5528_EN_1: R1103.2, R1104.1, U1101.4 (EN)
/BLOCK DIAGRAM/POWER SUPPLY/MIC5528_EN_2: R1106.2, R1107.1, U1102.4 (EN)
unnamed: L1101.1, R1101.2
unnamed: LED1101.1, R1102.1
unnamed: LED1102.1, R1105.1
unnamed: LED1103.1, R1108.1
unnamed: L1102.1, MOD1101.6 (+VO), TC1101.1, TC1102.1

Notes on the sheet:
+5VDC
500mA
260mA
350mA
1.5mA
PIC18F2X
TOTAL CURRENT CONSUMPTION
EXT. LEDS
150mA
Components
200mA
+3V3DC_1
FAN
15mA
OUTPUT = 500mA
976.5mA
+3V3DC_2
MIC5528_1
PCD8544
250mA
OUTPUT = 1A
MAX31855
MIC5528_2
KY-040

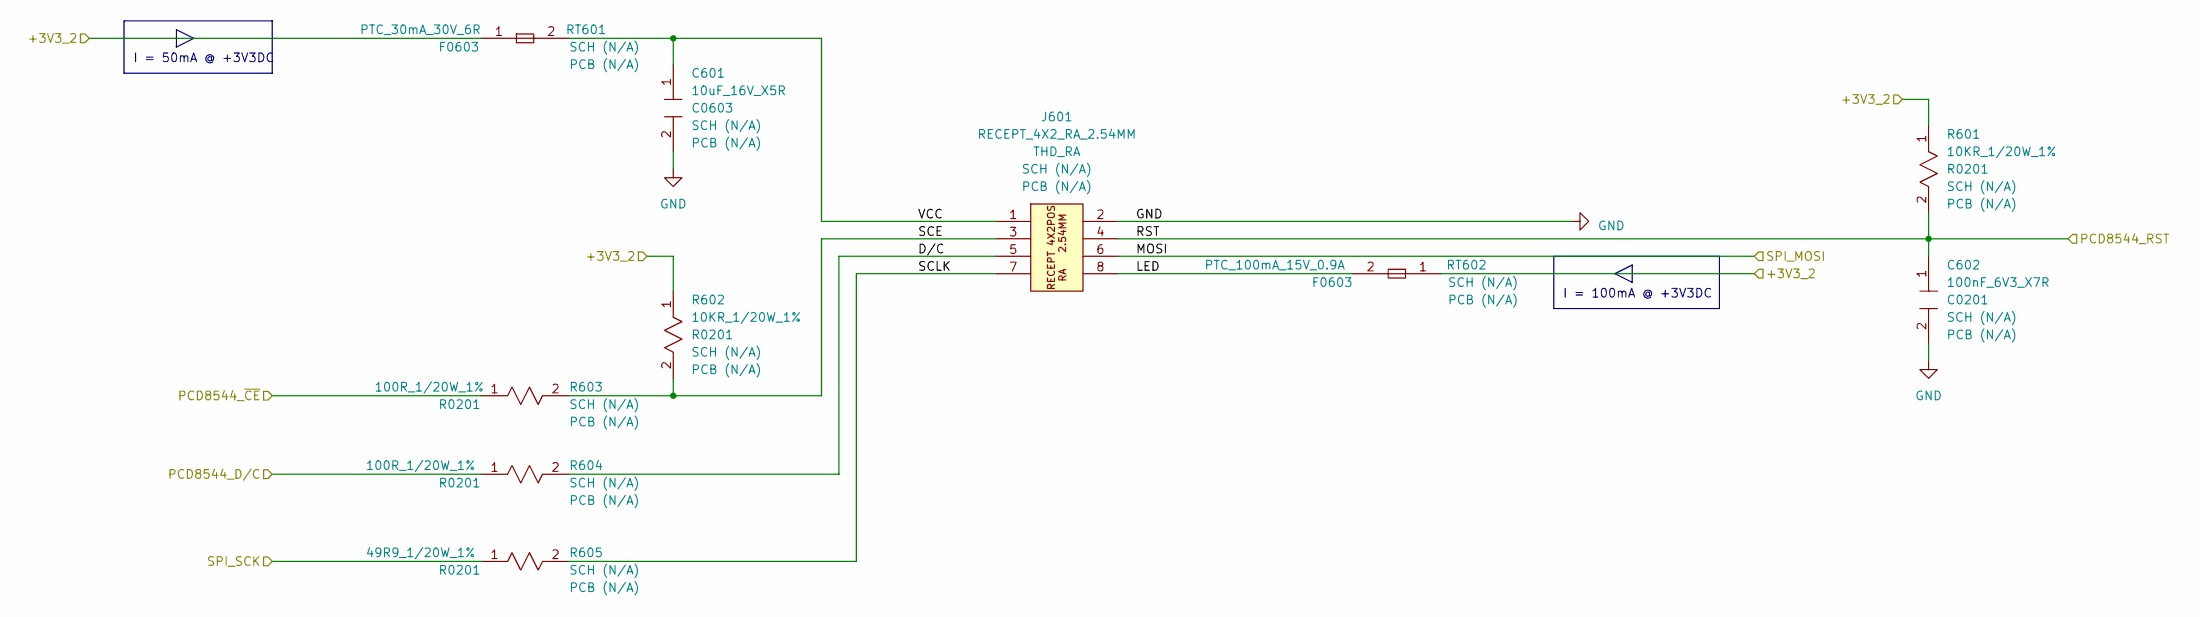
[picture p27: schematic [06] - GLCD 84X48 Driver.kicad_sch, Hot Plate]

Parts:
C601: 10uF_16V_X5R; C_0603_1608Metric; Part Number (Manufactur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 GRT188R61C106KE13J
C602: 100nF_6V3_X7R; C_0201_0603Metric; Part Number (Manufactur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 CC0201KRX7R5BB104
J601: RECEPT_4X2_RA_2.54MM; PinSocket_2x04_P2.54mm_Horizontal; Part Number (Manufactur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 PPTC042LJBN-RC
R601, R602: 10KR_1/20W_1%; R_0201_0603Metric; Part Number (Manufactur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 RMCF0201FT10K0
R603, R604: 100R_1/20W_1%; R_0201_0603Metric; Part Number (Manufactur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 RMCF0201FT100R
R605: 49R9_1/20W_1%; R_0201_0603Metric; Part Number (Manufactur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 RMCF0201FT49R9
RT601: PTC_30mA_30V_6R; Fuse_0603_1608Metric; Part Number (Manufactur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 0ZCM0003FF2G
RT602: PTC_100mA_15V_0.9A; Fuse_0603_1608Metric; Part Number (Manufactur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 0ZCM0010FF2G

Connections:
/BLOCK DIAGRAM/MICROCONTROLLER/PCD8544_D/C: R604.1; also elsewhere on the board
/BLOCK DIAGRAM/MICROCONTROLLER/PCD8544_~CE: R603.1; also elsewhere on the board
/BLOCK DIAGRAM/MICROCONTROLLER/SPI_SCK: R605.1; also elsewhere on the board
/BLOCK DIAGRAM/PCD8544 Driver/+3V3_2: R601.1, R602.1, RT601.1, RT602.1; also elsewhere on the board
/BLOCK DIAGRAM/PCD8544 Driver/D/C: J601.5, R604.2
/BLOCK DIAGRAM/PCD8544 Driver/LED: J601.8, RT602.2
/BLOCK DIAGRAM/PCD8544 Driver/MOSI: J601.6; also elsewhere on the board
/BLOCK DIAGRAM/PCD8544 Driver/RST: C602.1, J601.4, R601.2; also elsewhere on the board
/BLOCK DIAGRAM/PCD8544 Driver/SCE: J601.3, R602.2, R603.2
/BLOCK DIAGRAM/PCD8544 Driver/SCLK: J601.7, R605.2
/BLOCK DIAGRAM/PCD8544 Driver/VCC: C601.1, J601.1, RT601.2

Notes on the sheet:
I = 100mA @ +3V3DC
I = 50mA @ +3V3DC

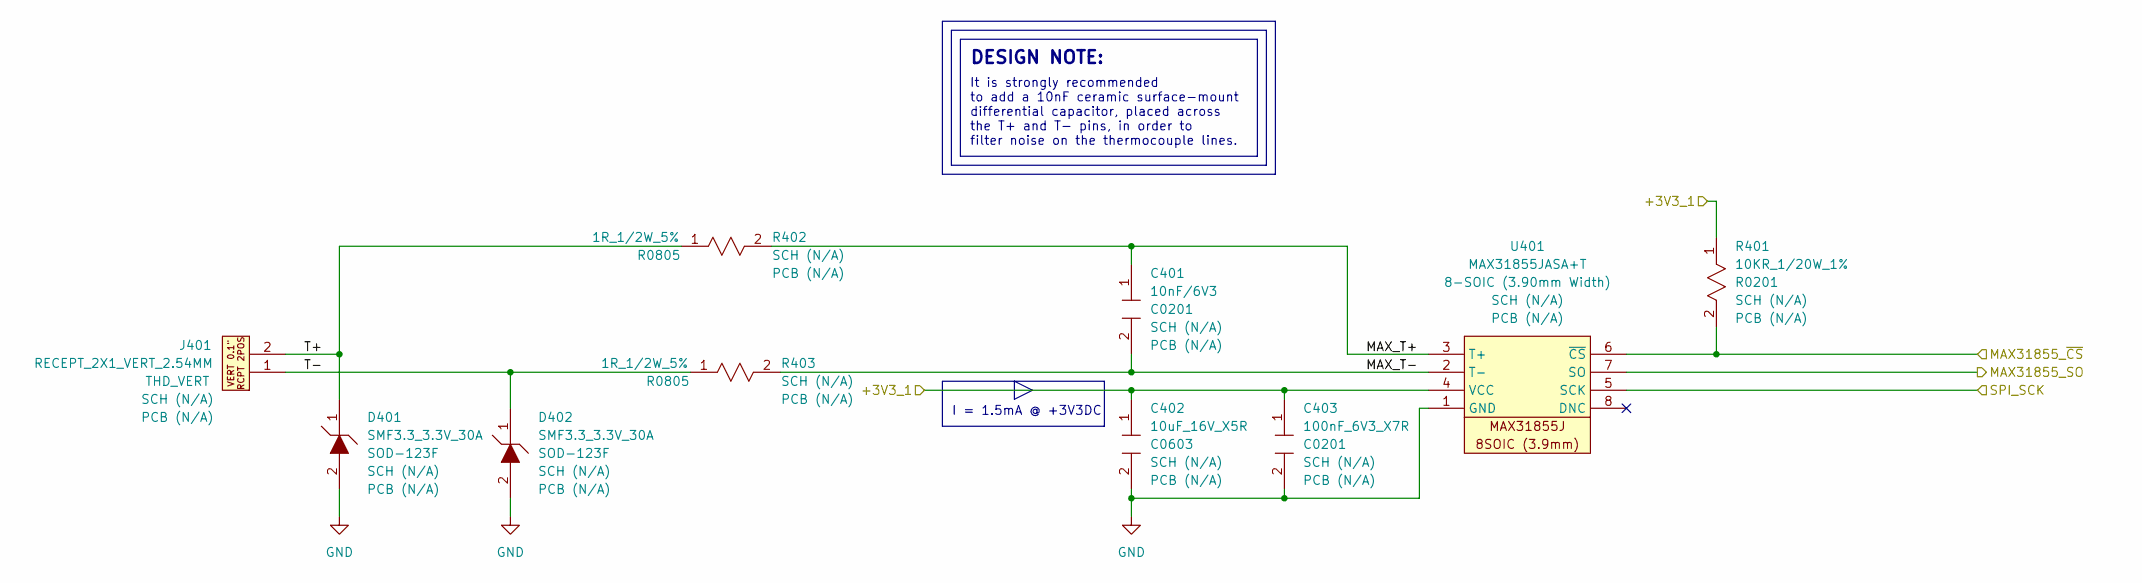
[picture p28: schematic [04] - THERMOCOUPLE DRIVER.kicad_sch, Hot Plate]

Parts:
C401: 10nF/6V3; C_0201_0603Metric; Part Number (Manufactur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 0201B103K6R3CT
C402: 10uF_16V_X5R; C_0603_1608Metric; Part Number (Manufactur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 GRT188R61C106KE13J
C403: 100nF_6V3_X7R; C_0201_0603Metric; Part Number (Manufactur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 CC0201KRX7R5BB104
D401, D402: SMF3.3_3.3V_30A; D_SOD-123F; Part Number (Manufactur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 SMF3.3
J401: RECEPT_2X1_VERT_2.54MM; PinSocket_1x02_P2.54mm_Vertical; Part Number (Manufactur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 RS1-02-G
R401: 10KR_1/20W_1%; R_0201_0603Metric; Part Number (Manufactur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 RMCF0201FT10K0
R402, R403: 1R_1/2W_5%; R_0805_2012Metric; Part Number (Manufactur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 SG73P2ATTD1R0J
U401: MAX31855JASA+T; SOIC-8_3.9x4.9mm_P1.27mm; Part Number (Manufactur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 MAX31855JASA+T

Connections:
/BLOCK DIAGRAM/ISOLATED TRIAC DRIVER/+3V3_1: C402.1, C403.1, R401.1, U401.4 (VCC); also elsewhere on the board
/BLOCK DIAGRAM/MICROCONTROLLER/MAX31855_SO: U401.7 (SO); also elsewhere on the board
/BLOCK DIAGRAM/MICROCONTROLLER/MAX31855_~CS: R401.2, U401.6 (~CS); also elsewhere on the board
/BLOCK DIAGRAM/MICROCONTROLLER/SPI_SCK: U401.5 (SCK); also elsewhere on the board
/BLOCK DIAGRAM/THERMOCOUPLE DRIVER/MAX_T+: C401.1, R402.2, U401.3 (T+)
/BLOCK DIAGRAM/THERMOCOUPLE DRIVER/MAX_T-: C401.2, R403.2, U401.2 (T-)
/BLOCK DIAGRAM/THERMOCOUPLE DRIVER/T+: D401.1, J401.2, R402.1
/BLOCK DIAGRAM/THERMOCOUPLE DRIVER/T-: D402.1, J401.1, R403.1

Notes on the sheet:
DESIGN NOTE:
I = 1.5mA @ +3V3DC
It is strongly recommended to add a 10nF ceramic surface-mount differential capacitor, placed across the T+ and T- pins, in order to filter noise on the thermocouple lines.

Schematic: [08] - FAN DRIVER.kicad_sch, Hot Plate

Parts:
D801: BAT60JFILM_10V_3A; D_SOD-323; Part Number (Manufactur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 BAT60JFILM
J903: RECEPT_2X1_VERT_2.54MM; PinSocket_1x02_P2.54mm_Vertical; Part Number (Manufactur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 RS1-02-G
Q801: AS3400; SOT-23; Part Number (Manufactur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 AS3400
R801: 100R_1/20W_1%; R_0201_0603Metric; Part Number (Manufactur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 RMCF0201FT100R
R802: 10KR_1/20W_1%; R_0201_0603Metric; Part Number (Manufactur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 RMCF0201FT10K0
RT801: PTC_100mA_15V_0.9A; Fuse_0603_1608Metric; Part Number (Manufactur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 0ZCM0010FF2G

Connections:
/BLOCK DIAGRAM/FAN DRIVER/EN_FAN: R801.1; also elsewhere on the board
unnamed: Q801.1, R801.2, R802.1

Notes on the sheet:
330uA @ +3v3DC
0.1A @ 4.5VDC

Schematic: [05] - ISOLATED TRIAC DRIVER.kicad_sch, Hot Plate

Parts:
D501: S1J_600V_1A; D_SMA; Part Number (Manufactur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 S1J
J501, J502: TERM_3POS_SIDE_5.08MM; TerminalBlock_Phoenix_MKDS-1,5-3-5.08_1x03_P5.08mm_Horizont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; Part Number (Manufactur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 EB147A-03-D
Q501: T2050H-6G-TR_600V_20A; TO-263-2; Part Number (Manufactur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 T2050H-6G-TR
R501: 10KR_1/20W_1%; R_0201_0603Metric; Part Number (Manufactur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 RMCF0201FT10K0
R502: 100KR_1W_1%; R_MELF_MMB-0207; Part Number (Manufactur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 SMM02070C1003FBP00
R503: 3KR_2W_1%; R_2512_6332Metric; Part Number (Manufactur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 35213K0FT
R504: 330R_1/10W_1%; R_0402_1005Metric; Part Number (Manufactur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 ERJ-2RKF3300X
U501: 140817143400; SMDIP-4_W7.62mm; Part Number (Manufactur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 140817143400
U502: MOC3022S; SMDIP-6_W7.62mm; Part Number (Manufactur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 MOC3022S

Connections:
/BLOCK DIAGRAM/ISOLATED TRIAC DRIVER/+3V3_1: R501.1; also elsewhere on the board
/BLOCK DIAGRAM/ISOLATED TRIAC DRIVER/EN_TRIAC: R504.1; also elsewhere on the board
/BLOCK DIAGRAM/ISOLATED TRIAC DRIVER/L_IN: J502.2, Q501.1, R502.2, R503.1; also elsewhere on the board
/BLOCK DIAGRAM/ISOLATED TRIAC DRIVER/L_OUT: J501.2, Q501.2
/BLOCK DIAGRAM/ISOLATED TRIAC DRIVER/MAIN_STROBE: R501.2, U501.4; also elsewhere on the board
/BLOCK DIAGRAM/ISOLATED TRIAC DRIVER/N: D501.1, J501.1, J502.3; also elsewhere on the board
Earth_Protective: J501.3, J502.1; also elsewhere on the board
unnamed: D501.2, U501.2
unnamed: Q501.3, U502.4
unnamed: R502.1, U501.1
unnamed: R503.2, U502.6
unnamed: R504.2, U502.1

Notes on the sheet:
input voltage
I = 6mA @ +3V3DC
+120V / +240V
+3V3DC
I = 1mA @ 110V
+110V
10mA @ 30 Vac 50mA @ 150 Vac 70mA @ 210 Vac (not very compatible with 240 Vac)
CLEAN SIDE
DESIGN NOTE: The Idea for finding the zero-crossing point is by capturing the positive peeks value and then derive the zero point IMPORTANT: Opto Ion = 1mA, Von = 0.9V, V Rectifier diode = 0.7V Von : (0.001A * 100KR) + 0.9 + 0.7 ~= +110V It's possible to figure out the frequency and working voltage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
-120V / -240V
MCU pin

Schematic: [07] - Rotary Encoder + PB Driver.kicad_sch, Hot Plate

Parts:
C701, C702, C704: 10uF_16V_X5R; C_0603_1608Metric; Part Number (Manufactur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 GRT188R61C106KE13J
C703: 100nF_6V3_X7R; C_0201_0603Metric; Part Number (Manufactur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 CC0201KRX7R5BB104
J701: RECEPT_5X1_RA_2.54MM; PinSocket_1x05_P2.54mm_Horizontal; Part Number (Manufactur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 PPTC051LGBN-RC
R701, R703, R705: 10KR_1/20W_1%; R_0201_0603Metric; Part Number (Manufactur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 RMCF0201FT10K0
R702, R704, R706: 100R_1/20W_1%; R_0201_0603Metric; Part Number (Manufactur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 RMCF0201FT100R
U701, U702, U704: SN74LVC1G17DBVR; SOT-23-5; Part Number (Manufactur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 SN74LVC1G17DBVR
U703: DLPT05A-7_5V_17A; SOT-23; Part Number (Manufactur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 DLPT05A-7

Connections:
/BLOCK DIAGRAM/ISOLATED TRIAC DRIVER/+3V3_1: C701.1, C702.1, C704.1, U701.5 (VCC), U702.5 (VCC), U704.5 (VCC); also elsewhere on the board
/BLOCK DIAGRAM/MICROCONTROLLER/ENCODER_PB: R706.2; also elsewhere on the board
/BLOCK DIAGRAM/MICROCONTROLLER/PIC18_ICSPPGC: R704.2; also elsewhere on the board
/BLOCK DIAGRAM/Rotary Encoder + PB Driver/KEY-040_B: J701.2, R703.2, U702.2 (A)
/BLOCK DIAGRAM/Rotary Encoder + PB Driver/KEY-040_SW: C703.1, J701.3, R705.2, U703.1, U704.2 (A)
unnamed: R702.1, U701.4 (Y)
unnamed: R704.1, U702.4 (Y)
unnamed: R706.1, U704.4 (Y)

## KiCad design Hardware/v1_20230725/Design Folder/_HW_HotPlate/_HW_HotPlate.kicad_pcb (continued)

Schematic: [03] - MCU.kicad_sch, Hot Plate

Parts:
C301, C302: 12pF_50V_C0G; C_0201_0603Metric; Part Number (Manufactur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 CC0201JRNPO9BN120
C303, C304, C306, C308, C309, C311: 100nF_6V3_X7R; C_0201_0603Metric; Part Number (Manufactur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 CC0201KRX7R5BB104
C305, C307, C310: 10uF_16V_X5R; C_0603_1608Metric; Part Number (Manufactur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 GRT188R61C106KE13J
D301: SMF3.3_3.3V_30A; D_SOD-123F; Part Number (Manufactur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 SMF3.3
J301: MHDR_4X1_RA_2.54MM; PinSocket_1x04_P2.54mm_Horizontal; Part Number (Manufactur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 PH1RB-04-UA
LED301: RED_2V_0.02A; LED_0402_1005Metric; Part Number (Manufactur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 B2841USD-20D001014U1930
R301: 49R9_1/20W_1%; R_0201_0603Metric; Part Number (Manufactur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 RMCF0201FT49R9
R302: 10KR_1/20W_1%; R_0201_0603Metric; Part Number (Manufactur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 RMCF0201FT10K0
R303: 100R_1/20W_1%; R_0201_0603Metric; Part Number (Manufactur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 RMCF0201FT100R
U301: PIC18F24J50-I/ML; QFN-28-1EP_6x6mm_P0.65mm_EP4.25x4.25mm_ThermalVias; Part Number (Manufactur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 PIC18F24J50-I/ML
U302, U303: SN74LVC1G17DBVR; SOT-23-5; Part Number (Manufactur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 SN74LVC1G17DBVR
X301: 16MHz_10ppm_12pF; Crystal_SMD_2016-4Pin_2.0x1.6mm; Part Number (Manufactur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 ECS-160-12-37B-CTN-TR

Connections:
/BLOCK DIAGRAM/FAN DRIVER/EN_FAN: U301.9 (RC1/T1OSI/UOE/RP12); also elsewhere on the board
/BLOCK DIAGRAM/ISOLATED TRIAC DRIVER/+3V3_1: C303.1, C307.1, C308.1, C309.1, C310.1, C311.1, R302.1, U301.11 (VUSB), U301.17 (VDD), U302.5 (VCC), U303.5 (VCC); also elsewhere on the board
/BLOCK DIAGRAM/ISOLATED TRIAC DRIVER/EN_TRIAC: U301.8 (RC0/T1OSO/T1CKI/RP11); also elsewhere on the board
/BLOCK DIAGRAM/ISOLATED TRIAC DRIVER/MAIN_STROBE: U301.21 (RB3/AN9/CTED2/VPO/RP6); also elsewhere on the board
/BLOCK DIAGRAM/LEDS DRIVER/SIG_LED_AMBER: U301.1 (RA2/AN2/VREF-/CVREF/C2INB); also elsewhere on the board
/BLOCK DIAGRAM/LEDS DRIVER/SIG_LED_BLUE: U301.28 (RA1/AN1/C2INA/RP1); also elsewhere on the board
/BLOCK DIAGRAM/LEDS DRIVER/SIG_LED_RED: U301.27 (RA0/AN0/C1INA/ULPWU/RP0); also elsewhere on the board
/BLOCK DIAGRAM/MICROCONTROLLER/ENCODER_PB: U301.18 (RB0/AN12/INT0/RP3); also elsewhere on the board
/BLOCK DIAGRAM/MICROCONTROLLER/EN_PWR: U301.10 (RC2/AN11/CTPLS/RP13); also elsewhere on the board
/BLOCK DIAGRAM/MICROCONTROLLER/MAX31855_SO: U301.23 (RB5/KBI1/SDI1/SDA1/RP8); also elsewhere on the board
/BLOCK DIAGRAM/MICROCONTROLLER/MAX31855_~CS: U301.14 (RC6/TX1/CK1/RP17); also elsewhere on the board
/BLOCK DIAGRAM/MICROCONTROLLER/PCD8544_D/C: U301.20 (RB2/AN8/CTED1/VMO/REFO/RP5); also elsewhere on the board
/BLOCK DIAGRAM/MICROCONTROLLER/PCD8544_~CE: U301.4 (RA5/AN4/SS1/HLVDIN/RCV/RP2); also elsewhere on the board
/BLOCK DIAGRAM/MICROCONTROLLER/PIC18_ICSPPGC: J301.3, U301.24 (RB6/KBI2/PGC/RP9); also elsewhere on the board
/BLOCK DIAGRAM/MICROCONTROLLER/PIC_OSC1: C301.1, U301.6 (OSC1/CLKI/RA7), X301.1
/BLOCK DIAGRAM/MICROCONTROLLER/PIC_OSC2: R301.2, U301.7 (OSC2/CLKO/RA6)
/BLOCK DIAGRAM/MICROCONTROLLER/PIC_SCK1: U301.22 (RB4/KBI0/SCK1/SCL1/RP7), U302.2 (A)
/BLOCK DIAGRAM/MICROCONTROLLER/PIC_SDO1: U301.15 (RC7/RX1/DT1/SDO1/RP18), U303.2 (A)
/BLOCK DIAGRAM/MICROCONTROLLER/PIC_VDDCORE: C305.1, C306.1, U301.3 (VDDCORE/VCAP(2))
/BLOCK DIAGRAM/MICROCONTROLLER/PIC_~MCLR: C304.1, D301.1, J301.1, R302.2, U301.26 (~MCLR)
/BLOCK DIAGRAM/MICROCONTROLLER/SPI_SCK: U302.4 (Y); also elsewhere on the board
/BLOCK DIAGRAM/MICROCONTROLLER/USB_DM: U301.12 (RC4/D-/VM); also elsewhere on the board
/BLOCK DIAGRAM/MICROCONTROLLER/USB_DP: U301.13 (RC5/D+/VP); also elsewhere on the board
/BLOCK DIAGRAM/PCD8544 Driver/MOSI: U303.4 (Y); also elsewhere on the board
/BLOCK DIAGRAM/PCD8544 Driver/RST: U301.19 (RB1/AN10/RTCC/RP4); also elsewhere on the board
unnamed: C302.1, R301.1, X301.3
unnamed: LED301.2, R303.2
unnamed: R303.1, U301.2 (RA3/AN3/VREF+/C1INB)

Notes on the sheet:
I = 250mA @ +3V3DC
DESIGN NOTE:
1: The on-chip voltage regulator is only available on parts designated with an “F”, such as PIC18F25J50. The on-chip regulator is disabled on devices with “LF” in their part number. 2: The VDDCORE/VCAP pin must never be left floating. On “F” devices, it must be connected to a capacitor, of size, CE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
ISCP PROGRAMMER PINS

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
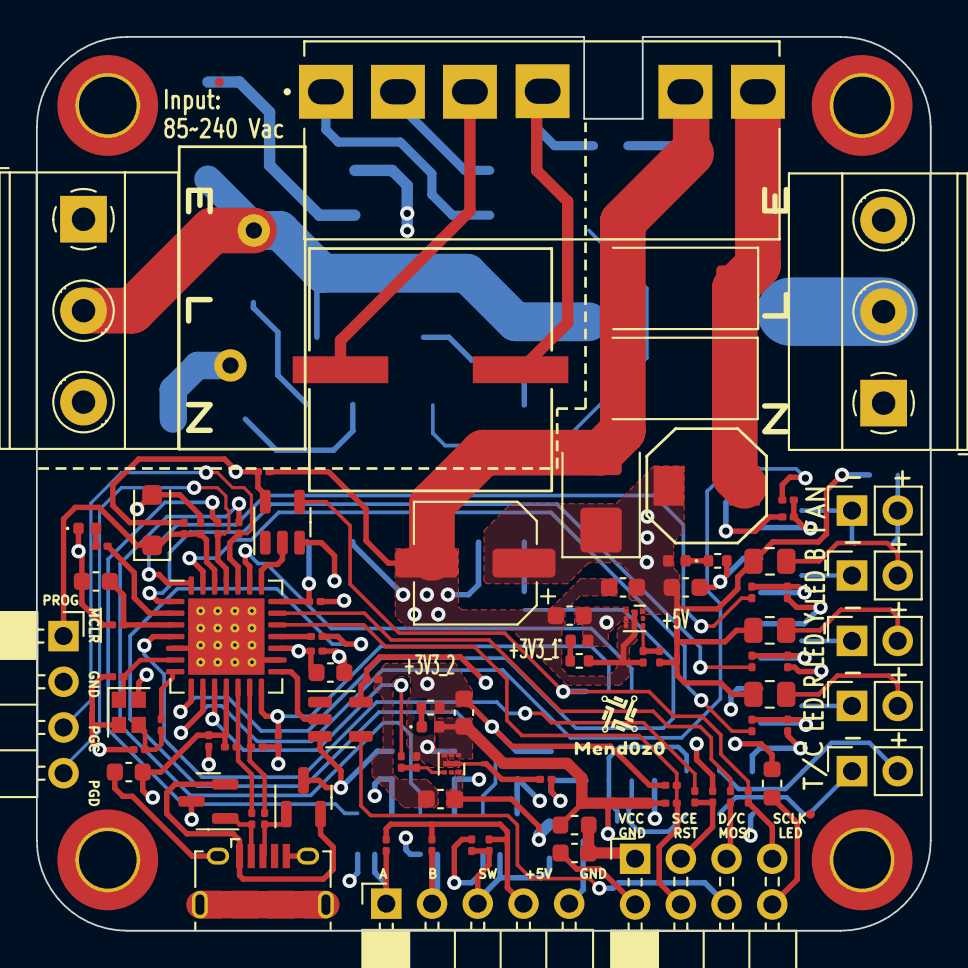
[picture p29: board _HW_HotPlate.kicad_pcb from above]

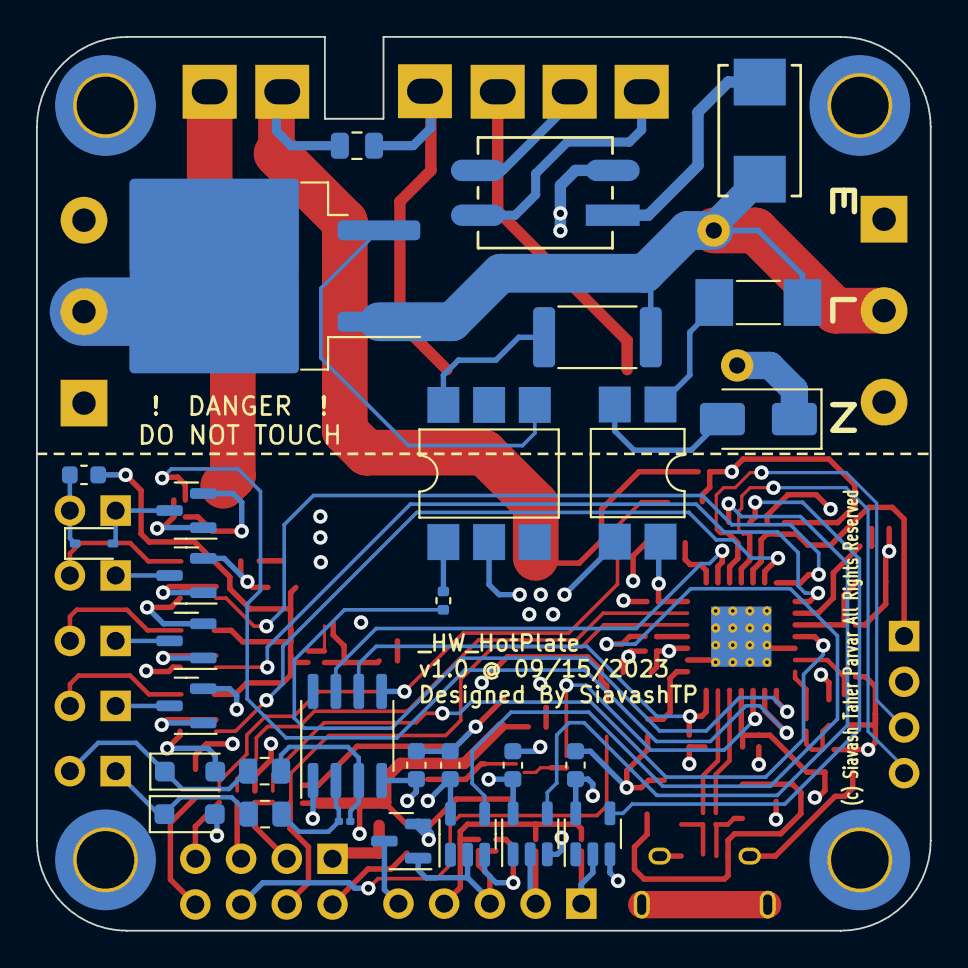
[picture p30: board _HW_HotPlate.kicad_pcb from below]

Board: 4 copper layers, 49.7 x 49.7 mm, 129 parts (30 on the bottom side), 82 nets.

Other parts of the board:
J801: RECEPT_2X1_VERT_2.54MM; PinSocket_1x02_P2.54mm_Vertical
R904, R905, R906: 100R_1/20W_1%; R_0201_0603Metric
R907, R908, R909: 10KR_1/20W_1%; R_0201_0603Metric

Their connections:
/BLOCK DIAGRAM/LEDS DRIVER/SIG_LED_AMBER: R905.1; also elsewhere on the board
/BLOCK DIAGRAM/LEDS DRIVER/SIG_LED_BLUE: R906.1; also elsewhere on the board
/BLOCK DIAGRAM/LEDS DRIVER/SIG_LED_RED: R904.1; also elsewhere on the board

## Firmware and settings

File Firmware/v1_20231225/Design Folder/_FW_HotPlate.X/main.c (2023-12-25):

/****************************************************************************************************
*
*   Project Name:       _FW_HotPlate
*   @Brief Description: This project will be used for home reflow soldering process
*   File Status:	    DRAFT   (DRAFT , PRELIMINARY, CHECKED, RELEASED)
*
*	File Name:	main.c
*	Version:	01
*	Revision:	00
*	Date:		2023/12/25
*	License:	Open-source
*	******************************** Project Description *******************************************
*	@Detailed Description: Hot plate project's purpose is to control the temperature of a hot plate
*   that is used for reflow soldering of PCBs at small numbers. The graph will be set manually or by
*   computer via USB. This firmware will control a Triac with PWM (to control the heating element 
*   of a hot plate), a fan with PWM (to cool down the plate), some LEDs (to display the status), and
*   an LCD (for writing text and displaying graph and time). The inputs are thermocouple sensor module
*  (for measuring plate temperature), rotary encoder (for working manually with device), and a USB 
*   to receive parameters from an application/software.
* 
*	******************************** File Description *******************************************
*	@Detailed Description:
*
*
*	*********************************  Hardware Info  **********************************************
*   Name:       _HW_HotPlate
*   Version:    v1.0
*	*********************************  Processor Info **********************************************
*	Processor:          PIC18F24J50 (8-Bits)
*	Clock Frequency:    48.00	MHz
*	RAM/SRAM Size:      03.80	KBytes
*	Flash Size:         16.00	KBytes
*
*	***********************************  Case Style  ***********************************************
*	Local Variables = camelCase			Global Variables = g_camelCase
*	Headers = SCREAMIN_SNAKE_CASE
*   Macros = SCREAMING_SNAKE_CASE
*   Const Variables = SCREAMING_SNAKE_CASE
*	Functions = PascalCase				Initialize Functions = _lower_case
*	Struct = lower_case					Struct.members = camelCase
*	Enum = lower_case					Enum Members = SNAKE_CASE
*	Pointer Variables = p_camelCase
*	*********************************** Contact Info ***********************************************
*	Author:	Siavash Taher Parvar
*	GitHub: github.com/Mend0z0
****************************************************************************************************/

/****************************************************************************************************
****************************       HEADERS DECLARATION       ****************************************
*****************************************************************************************************/
#include "main.h"
/****************************************************************************************************
****************************   GLOB. VARIABLES DECLARATION    ***************************************
*****************************************************************************************************/

/****************************************************************************************************
***********************     STATIC/LOCAL FUNCTIONS DECLARATION      *********************************
*****************************************************************************************************/
int main(void);

/****************************************************************************************************
****************************         GLOBAL FUNTIONS         ****************************************
*****************************************************************************************************/

/****************************************************************************************************
****************************         STATIC FUNTIONS         ****************************************
*****************************************************************************************************/

/****************************************************************************************************
*   @Brief Description: It's the main function of the project
*   Function Status: 	DRAFT   (DRAFT , PRELIMINARY, CHECKED, RELEASED)
*
*	************************************************************************************************
*	Function Name:          main()
*	Function Scope:         Local(static)
*	Function Parameters:    void
*	Function Return Type:   int
*	************************************************************************************************
*	@Detailed Description: (Do numbering and tag the number to each part of code)
*	(1)
*	(2)
*	(3)
*	.
*	.
*	.
*	************************************************************************************************
*	Revision History (Description (author, date: yyyy/mm/dd))
*
****************************************************************************************************/
int main( void ){
    
    while(1){
        
    }
    
    return 0;
}

/***************************************************************************************************/
/**********************************                             ************************************/
/********************                     END OF THE CODE                         ******************/
/**********************************                             ************************************/
/***************************************************************************************************/

/*                                   GLOBAL FUNCTION TEMPLATE                                      */

/****************************************************************************************************
*   @Brief Description:
*   Function Status: 	DRAFT   (DRAFT , PRILIMINARY, CHECKED, RELEASED)
*
*	************************************************************************************************
*	Function Name:
*	Function Scope:			Global
*	Function Parameters:
*	Function Return Type:
*	************************************************************************************************
*	@Detailed Description: (Do numbering and tag the number to each part of code)
*	(1)
*	(2)
*	(3)
*	.
*	.
*	.
*	************************************************************************************************
*	Revision History (Description, author, date: yyyy/mm/dd)
*
****************************************************************************************************/

/*                               STATIC/LOCAL FUNCTION TEMPLATE                                    */

/****************************************************************************************************
*   @Brief Description:
*   Function Status: 	DRAFT   (DRAFT , PRELIMINARY, CHECKED, RELEASED)
*
*	************************************************************************************************
*	Function Name:
*	Function Scope:         Local(static)
*	Function Parameters:
*	Function Return Type:
*	************************************************************************************************
*	@Detailed Description: (Do numbering and tag the number to each part of code)
*	(1)
*	(2)
*	(3)
*	.
*	.
*	.
*	************************************************************************************************
*	Revision History (Description (author, date: yyyy/mm/dd))
*
****************************************************************************************************/

/************************************     END OF THE FILE      *************************************/

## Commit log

2023-09-30 File restructuring
    [_MECH_HotPlate.cfg]
2023-10-01 Some cleanup
    [[02] - BLOCK DIAGRAM.kicad_sch, [03] - MCU.kicad_sch, [04] - THERMOCOUPLE DRIVER.kicad_sch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]
2023-11-20 Sorting documents
    [[02] - BLOCK DIAGRAM.kicad_sch, [03] - MCU.kicad_sch, [04] - THERMOCOUPLE DRIVER.kicad_sch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]
2023-12-27 Updating file naming
    [_HW_HotPlate.kicad_pcb]
2023-12-29 Schematic library has been updated
    [[02] - BLOCK DIAGRAM.kicad_sch, [03] - MCU.kicad_sch, [04] - THERMOCOUPLE DRIVER.kicad_sch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]
2023-12-29 components have been updated
    [[02] - BLOCK DIAGRAM.kicad_sch, [03] - MCU.kicad_sch, [04] - THERMOCOUPLE DRIVER.kicad_sch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]
2023-12-29 Updating hardware format structure
    [[02] - BLOCK DIAGRAM.kicad_sch, [03] - MCU.kicad_sch, [04] - THERMOCOUPLE DRIVER.kicad_sch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]
2023-12-29 Updating the symbols' structure
    [[03] - MCU.kicad_sch, [04] - THERMOCOUPLE DRIVER.kicad_sch, [05] - ISOLATED TRIAC DRIVER.kicad_sch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]
2024-01-04 Updating file structures
    [_HW_HotPlate.kicad_sch]
2024-01-07 Library updated
    [[03] - MCU.kicad_sch, [04] - THERMOCOUPLE DRIVER.kicad_sch, [06] - GLCD 84X48 Driver.kicad_sch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]
2024-01-13 Some try to check the working condition of assembled MCU
2024-01-15 Adding assembled pictures
2024-01-16 Updating assembled pictures
2024-01-17 Adding some items to todo list
    [[12] - MECHANICAL PARTS.kicad_sch]
2024-01-19 A little change in folder structures
    [[12] - MECHANICAL PARTS.kicad_sch]
2024-01-21 Designing the Mechanical parts
    [Schurter - 4304.6071 Power Entry Connector Receptacle wth Fuse.stp]
2024-01-23 Working on the 3D CAD model
    [_MECH_HotPlate_ASM.cfg]
2024-02-03 Working on 3D CAD model
    [HernanMH_LED 5mm Azul_.step, JesusMC_led 5mm v1.step, LCD Nokia 5110 Adafruit.SLDPRT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]
2024-02-04 3D CAD Model has been created
    [Banana Socket (Black).step, Banana Socket (Blue).step, Banana Socket (Red).step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]
2024-02-04 Some measurements have been added in PCB
    [_HW_HotPlate.kicad_pcb]
2024-02-04 Some more update to 3D CAD model
    [_MECH_HotPlate_ASM.cfg]

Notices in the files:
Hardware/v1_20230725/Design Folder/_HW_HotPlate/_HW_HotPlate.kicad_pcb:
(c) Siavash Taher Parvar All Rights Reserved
